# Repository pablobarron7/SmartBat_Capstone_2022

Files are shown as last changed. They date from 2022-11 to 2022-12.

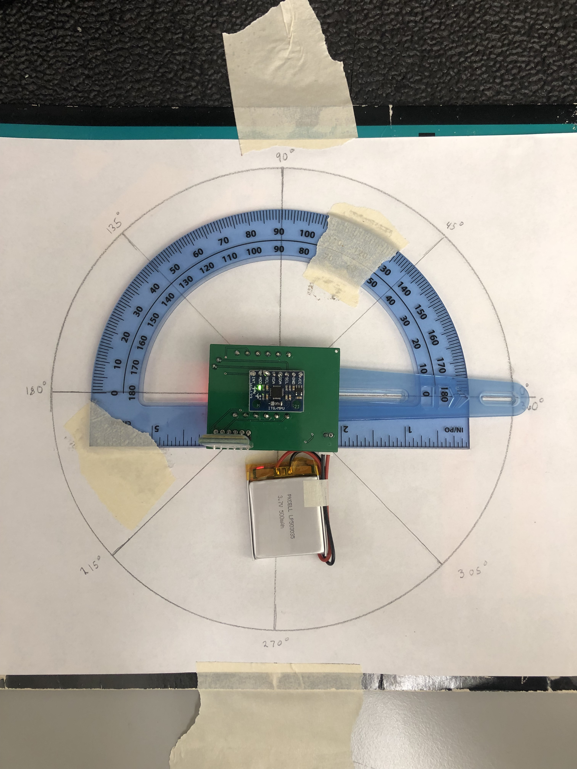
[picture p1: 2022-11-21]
IMU Validation Plots/GyroValidationMethod.jpg

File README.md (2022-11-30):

# SmartBat_Capstone_2022
  The purpose of this project is to allow a Cricket player to get real-time feedback on the user's swing data with out the need of assistance from a coach. The user will be able to view their efficiency, swing speed, and hit location on a user-friendly Android App. 
  
ANDROID APP SUBSYSTEM:
  
  The necessary source files for the android app are located under the "src" folder and include the "build.gradle" and "settings.gradle" files. The Andriod App receives data from our MCU via bluetooth which is then sent to an AWS cloud to be processed by the ML Model. The ML Model will then calcuate the hit location and swing speed. The app will then fetch the calculated results from our AWS Cloud.

CONTROL SUBSYSTEM:
  
  Download the SmartCricketBatOwnCode.ino file, along with the MCU libraries, and use both within Ardunio studio to flash desired ATmega328p microcontroller (make sure  MCU libraries are properly added to Arduino studio's directory after download to avoid any errors). Within the IMU Validation Plots folder are the results from several validation tests performed on the MPU-6050 inertial measurement unit, the plots prove the data recieved from the IMU is accurate, within some margin, to the expected results (raw data text files used to create plots are available within folder as well). 
  
POWER SUBSYSTEM:

  The "FinalPCB" folder contains the EAGLE schematic and PCB board layout files for the project. The PCB contains the battery charging circuit and boost converter circuit  which distribute all the necessary power to the control system. The "powersystemresults" folder contains results for the boost converter load test as well as results for the battery charging circuit.
  
ML SUBSYSTEM:

  All the necessary files are in the ML folder. WIth data collected, "Preprocessing321" to generate features and labels for trainnig the ML. They are named as "feature(1)" and "label(1)". With features and labels, you can traing the model with "Training321" and see the accuracy, heatmap, and feature importance(the seaborn pairplot is comment out). "model1.pkl" is the final model that we use for this project. "sv" is a python file as "sv.py" with stands for server version of my code where it will run on aws EC2 to predict the final results.

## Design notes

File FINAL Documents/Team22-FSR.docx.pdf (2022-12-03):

# Smart Cricket Bat

### Gavin Dahl, Jiakai Hu, Pablo Barron, Nolapat Pipitvitayakul

## FUNCTIONAL SYSTEM REQUIREMENTS

### REVISION – 2 18 November 2022

FUNCTIONAL SYSTEM REQUIREMENTS

FOR

## Smart Cricket Bat

PREPARED BY:

_____________________________
Author | Date

APPROVED BY:

_____________________________
Project Leader | Date

_____________________________
John Lusher, P.E. | Date

_____________________________
T/A | Date

Functional System Requirements | Revision - 2
The Smart Cricket Bat

### Change Record

Rev. | Date | Originator | Approvals | Description
- | 2/23/2022 | Gavin Dahl | | Draft Release
1 | 4/22/2022 | Gavin Dahl | | First Revision
2 | 11/18/2022 | Gavin Dahl | | Final Revision

### Table of Contents

List of Figures | 4
1. Introduction | 5
1.1. Purpose and Scope | 5
1.2. Responsibility and Change Authority | 5
2. Applicable and Reference Documents | 6
2.1. Applicable Documents | 6
2.2. Reference Documents | 6
2.3. Order of Precedence | 7
3. Requirements | 8
3.1. System Definition | 8
3.2. Characteristics | 9
3.2.1. Functional / Performance Requirements | 9
3.2.2. Physical Characteristics | 10
3.2.3. Electrical Characteristics | 11
3.2.4. Environmental Requirements | 13
3.2.5. Failure Propagation | 14
4. Support Requirements | 15
Appendix A Acronyms and Abbreviations | 16

### List of Figures

Figure 1. The Smart Cricket Bat Conceptual Image | 5
Figure 2. Block Diagram of System | 8

## 1. Introduction

### 1.1. Purpose and Scope

Our purpose is to help users improve their cricket skill through a training session using our system. The sensing unit will be attached to the end of the bat. This unit shall last for six hours of battery life after fully charged. The sensors will receive data and transfer them via bluetooth to an android phone app. The ML algorithm shall calculate the necessary data to the ones that need to be shown on the phone app like the hit location, swing angle and speed. The users shall be able to access these data through the phone app. The users will be able to know whether their hit was on the “sweet spot” or not as well as how efficient their swing was.

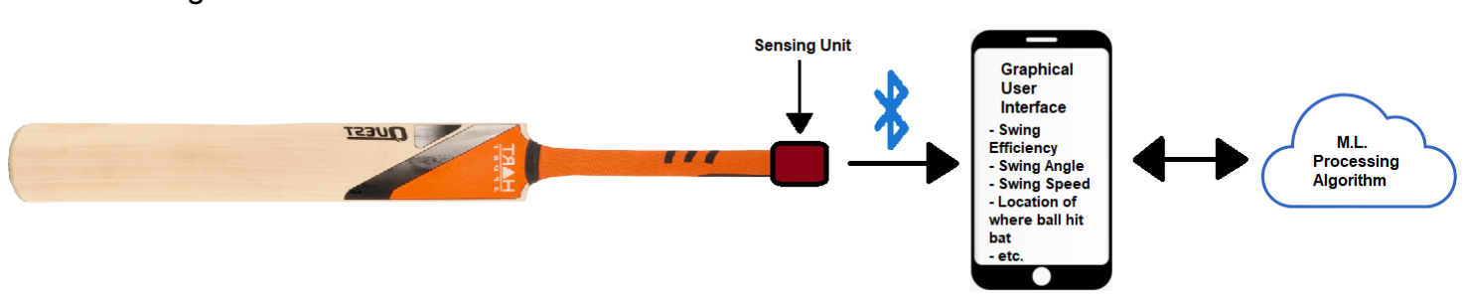
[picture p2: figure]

Figure 1. The Smart Cricket Bat Conceptual Image

### 1.2. Responsibility and Change Authority

Gavin Dahl has the responsibilities of making sure the team is sticking to the execution plan, completing milestones, and producing deliverables. He is also responsible for making the team confined to deadlines. The team's sponsor, Pranav Dhulipala, is the only one with the authority to make changes to the end goal requirements. If there is an unforeseen element that causes us to be unable to meet a requirement, Gavin and Pranav will discuss what will need to be done to change the requirement.

## 2. Applicable and Reference Documents

### 2.1. Applicable Documents

The following documents, of the exact issue and revision shown, form a part of this specification to the extent specified herein:

Document Number | Revision/Release Date | Document Title
IEEE 1780-2022 | 2022-02-09 | Standard for the Specification of Inertial Measurement Units
10.1109/ICIAFS.2008.4783 997 | 2009-02-13 | Design and Implementation of a Bluetooth based General Purpose Controlling Module
IEEE 802.15.1 | 2005-02-14 | Standard for Telecommunications and Information Exchange Between Systems
IEEE 802.15.4 | 2020-05-06 | Standard for Low-Rate Wireless Networks

### 2.2. Reference Documents

The following documents are reference documents utilized in the development of this specification. These documents do not form a part of this specification and are not controlled by their reference herein.

Link | Document Title
https://www.cricketequipmentusa.com/cricke t-bats-specifications-recent-changes-to-the-l aw-52#:~:text=Length%20and%20width%2 0of%20the,than%2052%25%20of%20the% 20bat (https://www.cricketequipmentusa.com/cricket-bats-specifications-recent-changes-to-the-law-52) | CRICKET BATS SPECIFICATIONS -RECENT CHANGES TO THE LAW
https://www.stancebeam.com/ | Stance Beam
https://www.google.com/url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 m%2Fpaper%2Fdownload%2F362441%2F mulchand_paper.pdf&usg=AOvVaw05RGQ GwEzXQR0SqdD7-Cp9 (https://cn.comsol.com/paper/download/362441/mulchand_paper.pdf) | Determination of the “Sweet Spot” of a Cricket Bat using COMSOL Multiphysics

### 2.3. Order of Precedence

In the event of a conflict between the text of this specification and an applicable document cited herein, the text of this specification takes precedence without any exceptions.

All specifications, standards, exhibits, drawings or other documents that are invoked as “applicable” in this specification are incorporated as cited. All documents that are referred to within an applicable report are considered to be for guidance and information only, except ICDs that have their relevant documents considered to be incorporated as cited.

## 3. Requirements

### 3.1. System Definition

In cricket, ball placement on the bat is very crucial to maximize the points you receive. To better improve a player's ball placement, we will design a device that can be attached to any cricket bat and predict the location of the collision between the bat and the ball. The device will be powered by a rechargeable lithium battery with a battery life of six hours. Data will then be gathered via a 3-axis accelerometer and gyroscope. A MCU will then send the data via bluetooth to an Android app to send to a server-based machine learning algorithm to predict the location of the collision. All results will then be displayed on the app.

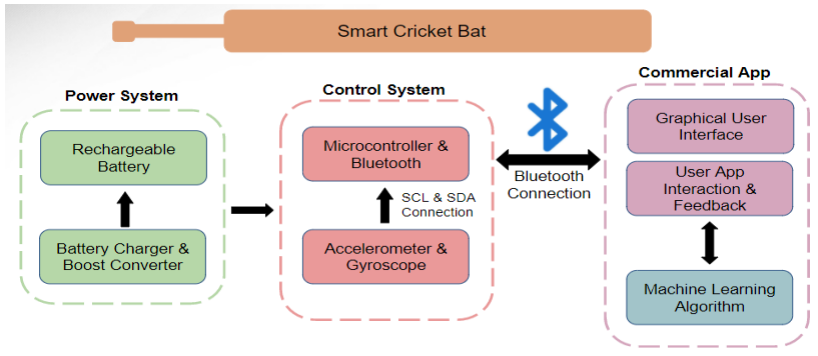
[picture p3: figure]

Figure 2. Block Diagram of System

The block diagram above shows the individual subsystems of the device. The subsystems include: Power System, Control System, and Commercial App. The device will be powered by a lithium battery connected to a boost converter to deliver the necessary power requirement for the control system. This battery will be connected to the control system through a PCB, that will also hold the charging circuit for the battery that will require a mircoUSB to charge. The control system encompasses a 3-axis accelerometer, a 3-axis gyroscope and a ATmega328p microprocessor. The angular momentum and rate of change data we measured with the gyroscope and accelerometer will then connect and be sent via bluetooth to the commercial app. The commercial app will then send the data to a machine learning algorithm via an internet connection to calculate collision location and efficiency. The results of the device will then be displayed on the easy to use app. Each output variable will have its own designated page to be viewed.

### 3.2. Characteristics

### 3.2.1. Functional / Performance Requirements

### 3.2.1.1. Calibration

The device must be able to be calibrated to properly calculate results. The process of calibration will entail leaving the device at rest in an upright position, and pushing the calibration button on the corresponding mobile app.

Rationale: The IMU sensor used in the device needs to be calibrated after start-up to deliver accurate and clean data to the machine learning algorithm. Calibrating the device
before usage will result in a higher certainty percentage.

### 3.2.1.2. Collision Location Determination

The main function of the device will be able to determine the location of the collision between the cricket bat and the ball based on the magnitude of the force felt by the bat and the torque produced by the ball on the bat, which is obtained from the data measured by the IMU sensor. The certainty must be at least 90%. This will require a machine learning (ML) algorithm.

Rationale: Cricket players will use the device to improve their swing efficiency. The location of the collision will dictate how far and in which direction the ball will go. Depending on where the ball lands on the field is how many turns (points) a player can achieve. Therefore, knowing where the ball collides with the bat is crucial for the player to know.

### 3.2.1.3. Efficiency Calculation

The device will be able to calculate how efficient the user is swinging the bat based on gathered data from previous swings. Efficiency is determined by how close the collision was to the “sweet spot” of the bat. The sweet spot of a cricket bat is located on the thickest section of the bat and is different for each cricket bat.

Rationale: Based on the efficiency the user will be able to tell how far off from the sweet
spot their swing is.

### 3.2.1.4. Bluetooth Range

The device will be able to communicate with the app within a range of 50m.

Rationale: The user should be able to do their practice swings with their phone clear from any danger of being hit while in the batting box.

### 3.2.1.5. Easy to Use App/GUI

The app will be easy navigable and easy to read the outputs

Rationale: The user might not have programming or data analysis skills so having an app that anyone can use and read is crucial for the device to be successful in the cricket market.

### 3.2.1.6. Battery Life

The device will be powered by a lithium battery that must have a battery life of 2 hours and must be rechargeable.

Rationale: Battery life and rechargeability were requirements set by the customer.

### 3.2.2. Physical Characteristics

### 3.2.2.1. Mass

The mass of the sensing unit that mounts to the handle of the cricket bat should be no more than 100g.

Rationale: This is a requirement specified by the sponsor due to wanting the device to be
as unobtrusive to the users swing as possible.

### 3.2.2.2. Volume Envelope

The volume envelope of the smart cricket bat’s sensor unit shall be less than or equal to 40mm in height, 70mm in outer diameter.

Rationale: This is a requirement specified by the sponsor due to wanting the device to be
as unobtrusive to the users swing as possible.

### 3.2.2.3. Mounting

The mounting device will attach to the bottom of the cricket bat’s handle and will have a locking mechanism with the sensor unit to give it a secure fit.

Rationale: The vibrations that occur from the impact of a swing can be quite intense. The requirement is to have the device stay on the bat at all times during the user's use, through any kind of outside interference.

### 3.2.3. Electrical Characteristics

### 3.2.3.1. Inputs

a. The presence or absence of any combination of the input signals in accordance with ICD specifications applied in any sequence shall not damage the smart cricket bat, reduce its life expectancy, or cause any malfunction, either when the unit is powered or when it is not.
b. No sequence of command shall damage the smart cricket bat, reduce its life expectancy, or cause any malfunction.

Rationale: By design, should limit the chance of damage or malfunction by user/technician error.

### 3.2.3.1.1 Power Consumption

The maximum peak power of the system shall not exceed 300 mW.

Rationale: This requirement is to ensure that enough power is being supplied to each of the components for at least 2 hours when the battery is fully charged.

### 3.2.3.1.2 Input Voltage Level

The input voltage level for the MCU and the IMU shall be +5 V.

Rationale: The microcontroller’s operating voltage is 5V and the IMU input voltage can be between 3.3V to 5V.

### 3.2.3.1.3 External Commands

The smart cricket bat shall document all external commands in the appropriate ICD.

Rationale: The ICD will capture all interface details from the low level electrical to the high-level packet format.

### 3.2.3.2. Outputs

### 3.2.3.2.1 Data Output via App

The app will be able to output data gathered from the accelerometer and gyroscope and the calculated results from the ML algorithm. The outputs will include: swing speed, swing angle, collision location, and efficiency. Each output will have its own page the user can navigate to via buttons on the home screen.

Rationale: By having an app that can constantly be gathering and outputting data in an
easy to read manner, it eliminates the need for the user to have tech. and data analysis skills. Without the app, users will have to download the data onto their computer to view
their results.

### 3.2.3.3. Connectors

The smart cricket bat will use a microUSB to charge the sensor unit, and will also be able to get the sensor data via a microUSB in the case of bluetooth not working.

Rationale: Most efficient way to make the device is to make it rechargeable, so that it
can be as small and light as possible.

### 3.2.3.4. Wiring

The smart cricket bat will use a PCB to connect all the internal components (MCU, IMU, Li-Po Battery, Boost Convertor/Charger) of the sensor unit.

Rationale: Normal wiring will most likely not be secure or robust enough for the amount
of shock that the device will encounter.

### 3.2.4. Environmental Requirements

The device will be adequate for indoor and outdoor use.

Rationale: Although the device will not be used during a cricket match, a user might be holding their practice session indoors or outdoors.

### 3.2.4.1. Pressure (Altitude)

The device will be designed to operate in 1 atm pressure.

### 3.2.4.2. Temperature

The device will be able to operate between temperature ranges of 0°C to 85°C.

Rationale: Since the device can be used outdoors, temperatures during the summer in Texas are between 97℉ - 105℉.

### 3.2.4.3. External Contamination

The device will be housed in a casing to protect the components from any dirt or foreign objects.

Rationale: Since the device can be used outdoors, it must be protected from any materials that can cause damage to the components.

### 3.2.4.4. Rain

The device will not be able to be used during the rain, but it should be waterproof enough to protect the components from the sweat of the user. The device will operate as intended within the humidity range of 0 to 80%, and should have the possibility of correct operation through 90 to 100%.

### 3.2.5. Failure Propagation

The smart cricket bat shall not allow propagation of faults beyond the app's interface.

### 3.2.5.1. Failure Detection, Isolation, and Recovery (FDIR)

### 3.2.5.1.1 Communication Test

The Smart Cricket Bat System shall provide users a notification if the user is using the system out of range or the internet/bluetooth connection is unstable at this moment.

### 3.2.5.1.1.1 BIT Critical Fault Detection

The BIT shall be able to detect a critical fault in the smart cricket bat’s sensing unit, machine learning algorithm, or consumer app, 95 percent of the time.

Rationale: This is to provide the best user experience we can, letting the user know that
we know there is an error and the system is working to fix it.

### 3.2.5.1.1.2 BIT False Alarms

The BIT shall have a false alarm rate of less than 5 percent.

Rationale: Due to some of the possible erroneous uses of the cricket bat, it might interpret an action of the user as an error, when in reality it is not.

### 3.2.5.1.1.3 BIT Log

The BIT shall save the results of each test to a log that shall be stored in the machine learning system for retrieval and will be used to improve common errors and overall quality of life of the user experience.

Rationale: The device is very user focused, so providing the best user experience is of
high priority.

### 3.2.5.1.2 Isolation and Recovery

The smart cricket bat should provide for fault isolation and recovery by enabling subsystems to be disabled based upon the result of the BIT.

Rationale: If there are any errors, we want to turn the device off and let the user know to
stop using it so they aren’t wasting energy on swings that will not be analyzed.

## 4. Support Requirements

The user will be provided with a user’s manual to know how to properly use the device. The user’s manual will encompass how to calibrate the device to be used in different sized cricket bats, the different functions of the app, ie. efficiency and swing speed, and how to charge the device. If any problems occur with the device, the user can send the device back to be fixed.

## Appendix A: Acronyms and Abbreviations

m | Meter
mm | Millimeter
mA | Milliamp
mAh | Milliamp-hour
mW | Milliwatt
V | Volt
MCU | Microcontroller
IMU | Inertial Measurement Unit (Accelerometer & Gyroscope)
PCB | Printed Circuit Board
LiPo | Lithium Polymer Battery
BLE | Bluetooth Low Energy
GUI | Graphical User Interface
BIT | Built-in-test

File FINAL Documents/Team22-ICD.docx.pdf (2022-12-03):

# Smart Cricket Bat

### Gavin Dahl, Jiakai Hu, Pablo Barron, Nolapat Pipitvitayakul

## INTERFACE CONTROL DOCUMENT

### REVISION – 1 18 November 2022

INTERFACE CONTROL DOCUMENT

FOR

## Smart Cricket Bat

PREPARED BY:

_____________________________
Author | Date

APPROVED BY:

_____________________________
Project Leader | Date

_____________________________
John Lusher II, P.E. | Date

_____________________________
T/A | Date

Interface Control Document | Revision - 1
Smart Cricket Bat

### Change Record

Rev. | Date | Originator | Approvals | Description
- | 2/23/2022 | Gavin Dahl | | Draft Release
1 | 11/18/2022 | Gavin Dahl | | Final Revision

### Table of Contents

List of Figures | 4
1. Overview | 4
2. References and Definitions | 5
2.1. References | 5
2.2. Definitions | 5
3. Physical Interface | 6
3.1. Weight | 6
3.2. Dimensions | 6
3.2.1. Dimensions of Power System | 6
3.2.2. Dimensions of Control System | 6
3.3. Mounting Locations | 6
4. Thermal Interface | 7
5. Electrical Interface | 8
5.1. Primary Input Power | 8
5.2. Signal Interfaces | 8
5.3. User Control Interface | 8
6. Communications / Device Interface Protocols | 9
6.1. Wireless Communications (Bluetooth & Internet ) | 9
6.2. G.U.I. | 9
6.3 | Device Peripheral Interface | 9

### List of Figures

Figure 1: Mounting Locations on Bat | 7
Figure 2: Sample UI | 10

## 1. Overview

In this ICD, the details for physical dimensions and weight will be provided in section 3. The sensing unit will be attached to the end of the bat, the details for attaching will also be provided. This unit does not have a cooling system. Temperature limits will be shown in section 4. This unit shall last for two hours of battery life after fully charged. The electrical details and thresholds for sensors and the whole system are listed in section 5. The details for communication between systems and the user control interface are provided in the last section.

## 2. References and Definitions

### 2.1. References

- Reference Device:
- https://www.stancebeam.com/
- Standard for the Specification of IMU’s:
- https://standards.ieee.org/ieee/1780/5700/
- Cricket Bat Standard:
- https://www.cricketequipmentusa.com/cricket-bats-specifications-recent-changes-to-the-law-52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,than%2052 %25%20of%20the%20bat. (https://www.cricketequipmentusa.com/cricket-bats-specifications-recent-changes-to-the-law-52)
- Determination of the “Sweet Spot” of a Cricket Bat using COMSOL Multiphysics
- https://www.google.com/url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 (https://cn.comsol.com/paper/download/362441/mulchand_paper.pdf)

### 2.2. Definitions

m | Meter
mm | Millimeter
mA | Milliamp
mAh | Milliamp-hour
mW | Milliwatt
V | Volt
MCU | Microcontroller
IMU | Inertial Measurement Unit (Accelerometer & Gyroscope)
LiPo | Lithium Polymer Battery
BLE | Bluetooth Low Energy
SCL | Serial Clock Line
SDA | Serial Data Line

## 3. Physical Interface

### 3.1. Weight

The goal is to keep the weight as low as possible, to not interfere with the players swing. The exact weight of the housing unit that will hold the components is still unknown, but ideally will be around 50 grams. The internal components of the device approximately add up to 40 grams. Weighing the device as a whole, including both the housing unit and the device internals, it will be less than 100 grams.

### 3.2. Dimensions

The mounting device's interior restriction is limited by the internal components of the device, which will be around 30mm x 35mm x 30mm. The exact dimensions of the housing unit for the device is still unknown, but basing them off the known restrictions for internals of the device, it should be approximately 35mm x 40mm x 35mm, with the goal being to make it a cylindrical mounting device that will have a diameter of about 60mm and height of 35mm.

### 3.2.1. Dimension of the power system

The power system itself, being composed of 1 Li-Po battery and 1 boost converter/recharging station, makes up approximately 33mm x 20mm x 14mm

### 3.2.2. Dimension of the control system

The control system is made up of 1 Beetle BLE MCU and 1 6-axis IMU sensor (containing a 3-axis gyroscope and a 3-axis accelerometer), totaling up to approximately 30mm x 35mm x 8mm.

### 3.3. Mounting Locations

The mounting location will be at the end of the cricket bat’s handle. It will use a kind of sleeve that is put over a little more handle and will securely lock together with the housing device for the control and power systems. If there are any complications with trying to mount the device in this location, the back up spot for mounting will be on the back of the bat at the other end of the handle.

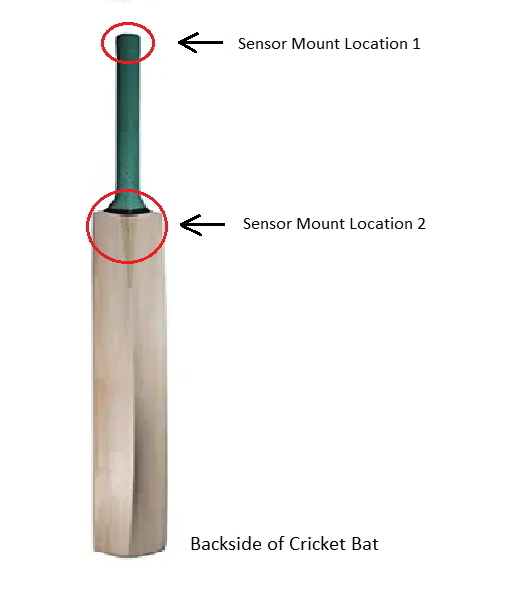
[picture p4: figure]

Figure 1: Mounting Locations on Bat

## 4. Thermal Interface

Since our device will be small enough to be attached to the bottom of a cricket bat, there will not be a need for fans or heat sinks for cooling. The only thermal interface our device will require is having vents or perforations on the main housing of the MCU and IMU’s to allow airflow, as the MCU is the limiting factor and cannot run properly over 85°C (185°F). This will prevent overheating in case the user is using our device outdoors on a summer’s day.

## 5. Electrical Interface

### 5.1. Primary Input Power

Power will be supplied by a rechargeable 3.7V lithium ion polymer battery with 500mAh capacity. The voltage will be regulated and the boost converter will convert the voltage to 5V, which is within the acceptable range of input voltage levels for the MCU and the sensors.

### 5.2. Signal Interfaces

The signal interfaces are the input to the MCU from the IMU sensor containing a 3-axis gyroscope and a 3-axis accelerometer. The IMU sensor module uses SCL/SDA for communicating with the microcontroller.

### 5.3. User Control Interface

The interface with the user will be an android app which will display the data collected by the IMU sensor as well as the data for the location of collision with the ball and the efficiency of the user’s swing predicted by a machine learning algorithm.

## 6. Communications / Device Interface Protocols

### 6.1. Wireless Communications (Bluetooth & Internet )

Our device will communicate with our app via bluetooth, which will have a connectivity range of about 50m. The app itself will also connect to our machine learning algorithm, that's stored in the cloud, via an internet connection.

### 6.2. GUI

All user interactions with our device will be controlled by an android app. These interactions will include calibration of our device and data output. The user will be able to navigate through different pages of the app via designated buttons on the home screen. A screen show of the buttons on the dashboard is shown below.

Figure 2: Sample UI

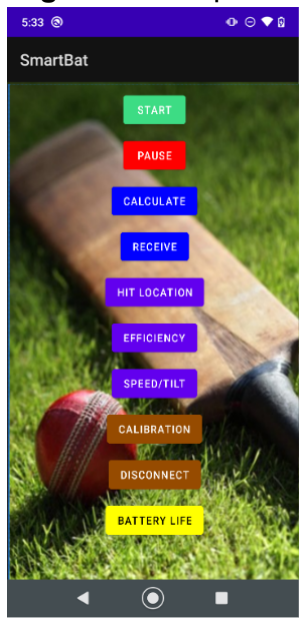
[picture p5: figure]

### 6.3. Device Peripheral Interface

The MCU and IMU will communicate with each other via a SCL and SDA connection. This connection allows the SCL to be the synchronized clock signal between the MCU and IMU for data transfer over the IC2 bus, and SDA is the data line that holds the actual data.

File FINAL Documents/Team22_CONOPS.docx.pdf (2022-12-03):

# Smart Cricket Bat

### Gavin Dahl, Jiakai Hu, Pablo Barron, Nolapat Pipitvitayakul

## CONCEPT OF OPERATIONS

### REVISION – 2 17 November 2022

CONCEPT OF OPERATIONS

FOR

## Smart Cricket Bat

TEAM <22>

APPROVED BY:

_____________________________
Project Leader | Date

_____________________________
Prof. Kalafatis | Date

_____________________________
T/A | Date

Concept of Operations | Revision - 2
Smart Cricket Bat

### Change Record

Rev. | Date | Originator | Approvals | Description
- | 2/9/2022 | Pablo Barron | | Draft Release
1 | 2/23/2022 | Pablo Barron | | First Revision
2 | 11/17/2022 | Gavin Dahl | | Final Revision

### Table of Contents

Table of Contents | 3
List of Figures | 4
1. Executive Summary | 6
2. Introduction | 7
2.1. Background | 7
2.2. Overview | 7
2.3. Referenced Documents and Standards | 7
3. Operating Concept | 8
3.1. Scope | 8
3.2. Operational Description and Constraints | 8
3.3. System Description | 8
3.4. Modes of Operations | 9
3.5. Users | 9
3.6. Support | 10
4. Scenario(s) | 11
4.1. Indoor Cricket Batting Practice | 11
4.2. Outdoor Cricket Batting Practice | 11
5. Analysis | 11
5.1. Summary of Proposed Improvements | 11
5.2. Disadvantages and Limitations | 11
5.3. Alternatives | 11
5.4. Impact | 12

### List of Figures

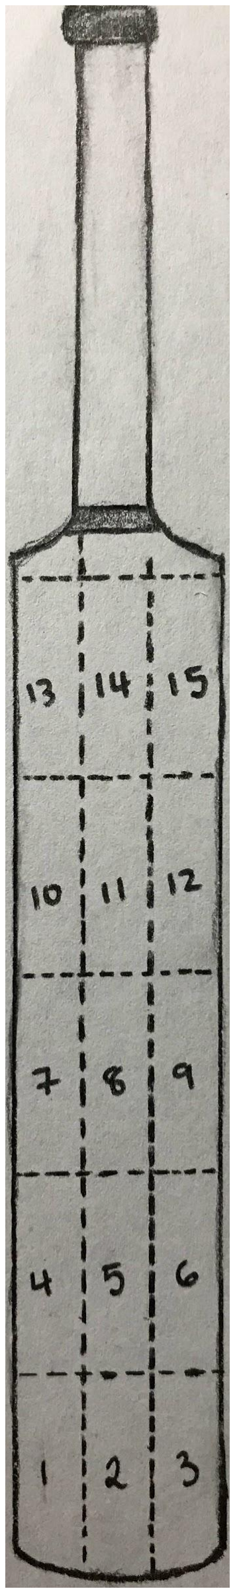
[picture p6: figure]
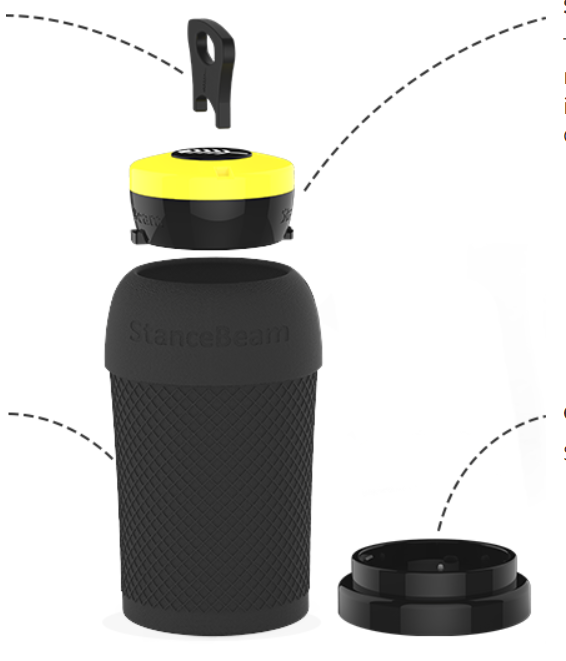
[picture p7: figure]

Fig. 1: Cricket Bat Region Subdivision Fig.2: StanceBeam Device Charging Dock on the right. Main hardware housing is in yellow. The mounting to attach to the bat below the main hardware housing. Figure above the main housing is to lock the device in place

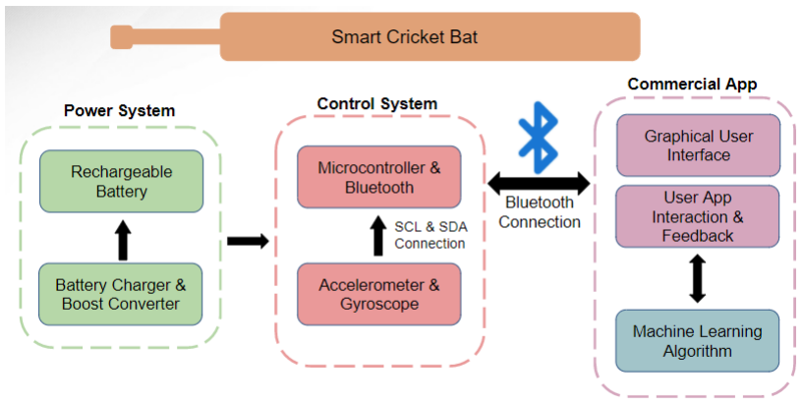
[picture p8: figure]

Fig.3: Subsystem Block Diagram

## 1. Executive Summary

While cricket has been around for much longer than its contemporary baseball, there is a stark difference in training equipment available for casual enjoyers, the smart cricket bat plans to fill that space. The smart cricket bat offers an easy at home alternative to coaching lessons in the form of an app and a device you put on your cricket bat of choice. The app will display measurements and calculations from the bat, such as the angle of the swing, the speed of the swing, the efficiency of the user’s swing, and the approximate position of where the ball hit the bat. The last of which is found via a machine learning algorithm that takes the other measurements and triangulates the impact location. This will help improve both accuracy and precision when swinging for the bats sweet spot.

## 2. Introduction

Cricket is more of a niche sport than others, so it’s no surprise that the community overall is lacking in training and feedback equipment. Most of the training equipment they do have are primarily rudimentary items, such as ball rebounders, batting tees, etc. And recently, one start up, StanceBeam, that is trying to provide easier at home training is a little on the expensive side. The smart cricket bat will fill this gap by providing a device that will attach to the user’s cricket bat of choice and acquire various data points on each swing. This device will then connect to the player's phone via bluetooth, process the data acquired from the sensors on the bat, and give real time feedback to help the user.

### 2.1. Background

In cricket, the goal is to score runs, this is accomplished through completing runs, hitting boundaries, losing wickets, and free runs. Half of these, completing runs and hitting boundaries, involve hitting the ball into a desired area of the field, to accomplish these feats easier the cricket bat is designed to have a “sweet spot” where the bat is thicker than everywhere else, thus having more force behind it. The goal is to have a consistent enough swing to hit the sweet spot as often as possible. StanceBeam is a start-up out of India that is trying to help the average player with this. Their product is a sensor that connects to an app and displays measurements from the bat such as swing angle, swing speed, power generated from swing, and overall swing efficiency. The app also has drills and real-time coaching from real coaches to help improve aspects of their play. In contrast, the app will display where the ball impacted the bat via a histogram and give advice for improvement, as well as displaying swing angle, swing speed, and overall swing efficiency. Despite being limited in the ability to display drills or video analysis, the Smart Cricket Bat will be able to help the user improve swing consistency and ball placement, specifically for the bats sweet spot, through the use of small advice and a histogram from swing data.

### 2.2. Overview

The overall goal of the smart cricket bat is to deliver concise, analyzed data from the users swings to the app and give real-time feedback to the user to help improve their overall swing consistency and efficiency. This will be accomplished by a device that will mount to the end of the cricket bats handle and collect both speed and angle of the cricket bat during the user swing. It then sends that data to the smartphone app via bluetooth to process the data, through a machine learning algorithm, and output real time feedback to the user.

### 2.3. Referenced Documents and Standards

- Reference Device:
- https://www.stancebeam.com/
- Standard for the Specification of IMU’s:
- https://standards.ieee.org/ieee/1780/5700/
- Cricket Bat Standard:

- https://www.cricketequipmentusa.com/cricket-bats-specifications-recent-changes-to-the-law-52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,than%2052 %25%20of%20the%20bat. (https://www.cricketequipmentusa.com/cricket-bats-specifications-recent-changes-to-the-law-52)
- Determination of the “Sweet Spot” of a Cricket Bat using COMSOL Multiphysics
- https://www.google.com/url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 (https://cn.comsol.com/paper/download/362441/mulchand_paper.pdf)

## 3. Operating Concept

### 3.1. Scope

The main functionality of the smart cricket bat will be to calculate where on the bat the ball hits based on data gathered from a gyroscope and an accelerometer. Based on data collected from the gyroscope and accelerometer, the speed of the swing and angle of the swing will be calculated by an offline machine learning algorithm. The data gathered from the IMU sensors will be sent via bluetooth to an app. From the gathered data and ML algorithm results, the app will display to the user with a histogram of where on the bat the ball collided. From the data on the histogram, how efficient the user is hitting the ball will be calculated. The app will also show details of every swing ie. speed of the swing and swing angle.

### 3.2. Operational Description and Constraints

The device will be attached on the bottom of the handle of the bat. Once the device is attached, it will need to be calibrated to accurately measure collision location and efficiency. The calibration of the device will be the main constraint, since failure to properly calibrate the device will lead to false data being produced. The calibration step will be a simple button press while the bat is resting in an upright position. Once calibrated, the user will be able to practice for about six hours on full battery. During the user’s practice session or after the session, the user can check the app to view the data gathered for each swing. Once the battery is drained or the user’s practice session is finished, the user will need to recharge the device via a micro-USB cable. Another constraint for the device is size and weight. The device must be small enough to attach to the bottom of the handle on the cricket bat and light enough to not affect the overall feel of the bat and performance of the user.

### 3.3. System Description

- Power: The device will be powered by a lithium battery with a battery life of about six hours. The device will be rechargeable via a micro-USB cable.
- Sensors and Microcontroller: The sensors (IMU) will encompass one 3-axis accelerometer and one 3-axis gyroscope. The device will gather the angular velocity and rate of change from the IMU and transfer data via bluetooth to be processed in a machine learning algorithm.

- App: The app will receive data from the MCU and send the data to an offline machine learning algorithm to calculate and predict the location of collision and the efficiency of the user’s swing. Once the region of collision and efficiency is determined, the app will display a histogram of the different collisions that occurred during the user’s training session. It will also display the swing speed, swing angle, and efficiency of the user.

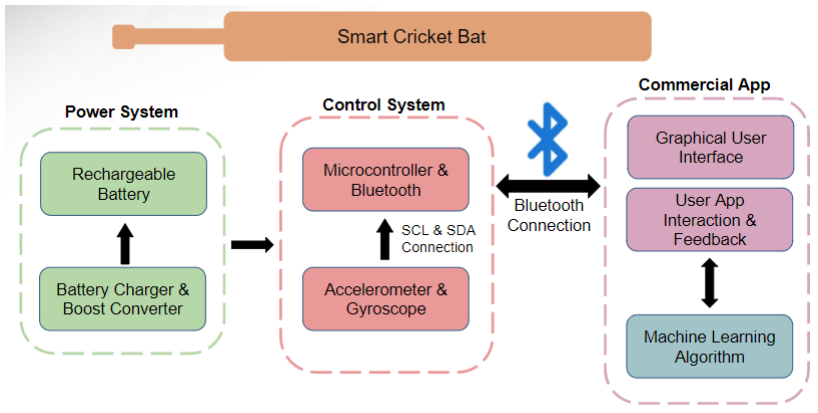
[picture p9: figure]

Figure 1: Subsystem block diagram

### 3.4. Modes of Operations

The device will have two modes of operation:
- Calibration Mode: Before the user can use the device, the device needs to be calibrated, doing so is as simple as pushing a button on the mobile application while the device is at rest in the upward position.
- Practice Mode: Once the device is calibrated, the user is now able to begin their training session. The device will have a six hour battery life. During the training session, the microprocessor will send data gathered from the IMU to the app to be sent to a server housing the machine learning algorithm to determine the location of collision and the efficiency of the user. The app will then display a histogram to show the collision location of each swing, the speed of the swing, swing angle, and user’s efficiency.

### 3.5. Users

The main users will be cricket players trying to improve their swing. Their experience with cricket will range from grade-school level to professional players. The necessary skill level to operate the device is knowing how to use a phone app and read a histogram.

### 3.6. Support

The user will be provided with a user’s manual to know how to properly use the device. The user’s manual will encompass how to calibrate the device to be used in different sized cricket bats, the different functions of the app, ie. efficiency and swing speed, and how to charge the device. If any problems occur with the device, the user can send the device back to be fixed.

## 4. Scenario(s)

### 4.1. Indoor Cricket Batting Practice

The first scenario for the smart cricket bat is the user uses the device to practice their swing in an indoor training environment. In this scenario, the only potential damage that the device will encounter is the energy transfer of the ball and the bat colliding and potential sweat from the user. The device will have to be able to work efficiently under these conditions

### 4.2. Outdoor Cricket Batting Practice

The second scenario is if the user wants to use the device to practice their swing in an outdoor training environment. In this scenario, many potential damages can occur. The device will need to not only withstand the conditions of the indoor scenario, but also take into account dirt, water, and extreme temperatures, for both cold and heat.

## 5. Analysis

### 5.1. Summary of Proposed Improvements

The device will offer a user-friendly app and system to allow them to increase the efficiency of their swing by seeing real time data and details on each swing. This device will be able to work on any size of cricket due to the required calibration mode prior to beginning a practice session.

### 5.2. Disadvantages and Limitations

- There is a limitation to the size of the system because it should be small enough to fit on to the bottom of the cricket bat handle.
- Unable to record video for each swings and analyze the video
- The device cannot be too heavy to disrupt the feel of a natural cricket bat
- Every user hold the bat differently, which can cause inconsistencies in the data collection and calculations

### 5.3. Alternatives

- The sensors could be attached to the back of the cricket bat instead of on the handle if size is an issue. Although we opposed from using this design due to a high risk of damaging the sensors due to the energy transfer from the collision of the ball and the cricket bat
- Additional sensors can be added to improve the accuracy of the results.

### 5.4. Impact

- This project will help cricket players study and improve the user’s batting performance.
- If the device becomes as popular as cricket, it can cause an increase in the need for lithium batteries. This higher demand will then cause the mining of lithium and other raw metals to increase.
- The device has the potential to reduce the need for cricket trainers.

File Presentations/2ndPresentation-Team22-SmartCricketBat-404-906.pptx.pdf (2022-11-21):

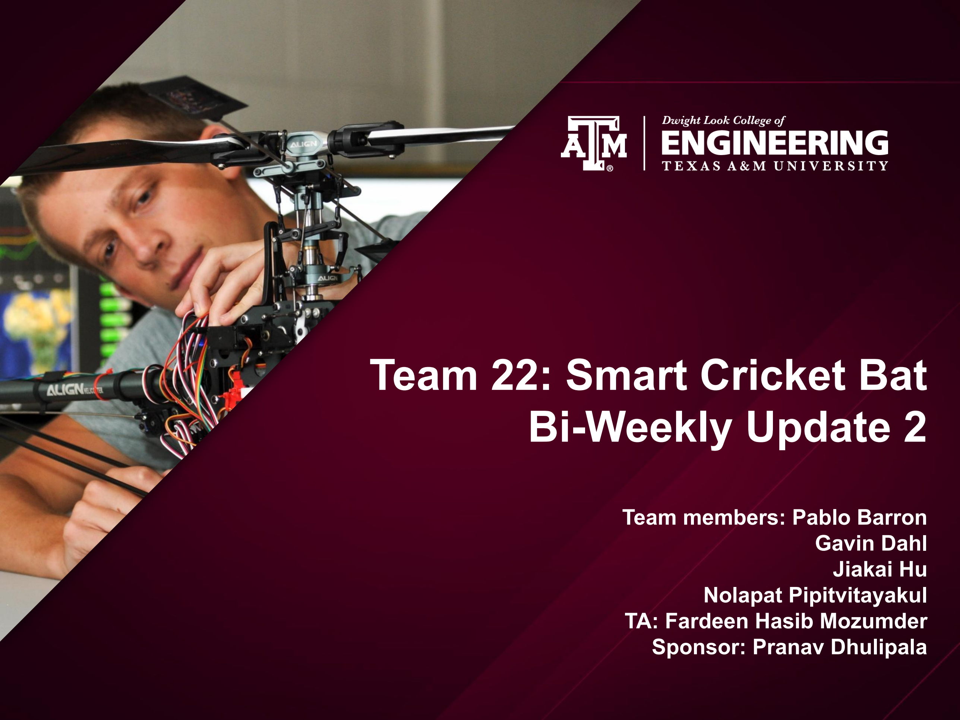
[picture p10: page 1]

# Team 22: Smart Cricket Bat Bi-Weekly Update 2

Team members: Pablo Barron Gavin Dahl
Jiakai Hu
Nolapat Pipitvitayakul
TA: Fardeen Hasib Mozumder Sponsor: Pranav Dhulipala

# Project description

## - Problem: “Cricket practice equipment lacks effectiveness without the assistance and guidance of a coach”

## - Solution proposal: “Create a device that will mount on the cricket bat and, through a user friendly app, gives real time feedback on the user’s cricket swing i.e. efficiency and swing angle. Must be easy to use and set up”

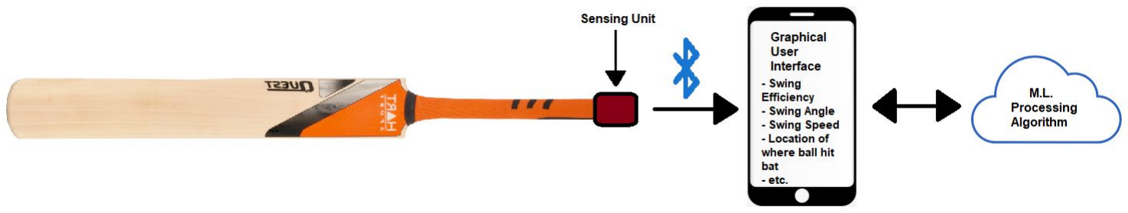
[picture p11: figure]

# Diagram of subsystems and interface

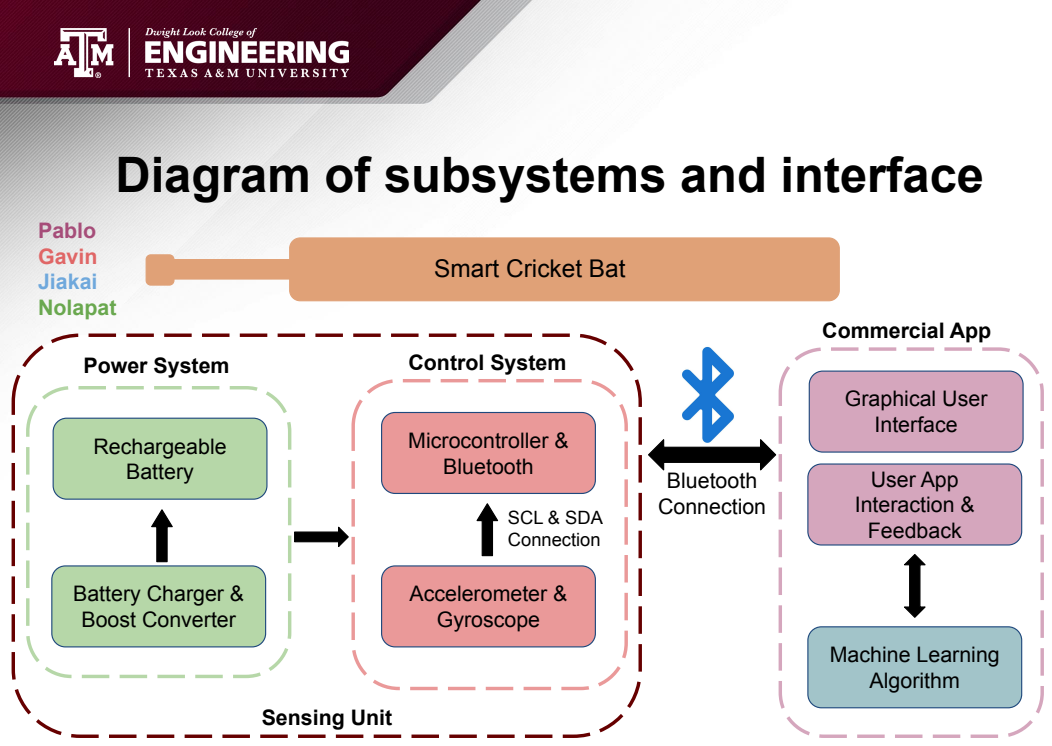
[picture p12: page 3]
Rechargeable; Battery; User App; Interaction & Feedback; Machine Learning Algorithm; Microcontroller & Bluetooth; Accelerometer & Gyroscope; Battery Charger & Boost Converter; Bluetooth Connection; Power System; Control System; Commercial App; Graphical User Interface; Pablo Gavin Jiakai Nolapat; SCL & SDA Connection; Sensing Unit

Smart Cricket Bat

# Subsystem Overview

# - Android App: Will handle user interaction and

communication between the MCU and the ML algorithm.

The app receives data from the MCU via a bluetooth connection. The app will then send received data to ML algorithm to be processed - Power: Contains the boost-converter, on-board lithium battery power supply, and recharging station - ML Algorithm: Develop the ML algorithm for finding the specific characteristics of users swing - Control : A sensing unit that will communicate the IMU values from the swing to the user app through an MCU with bluetooth capabilities

# Project Timeline

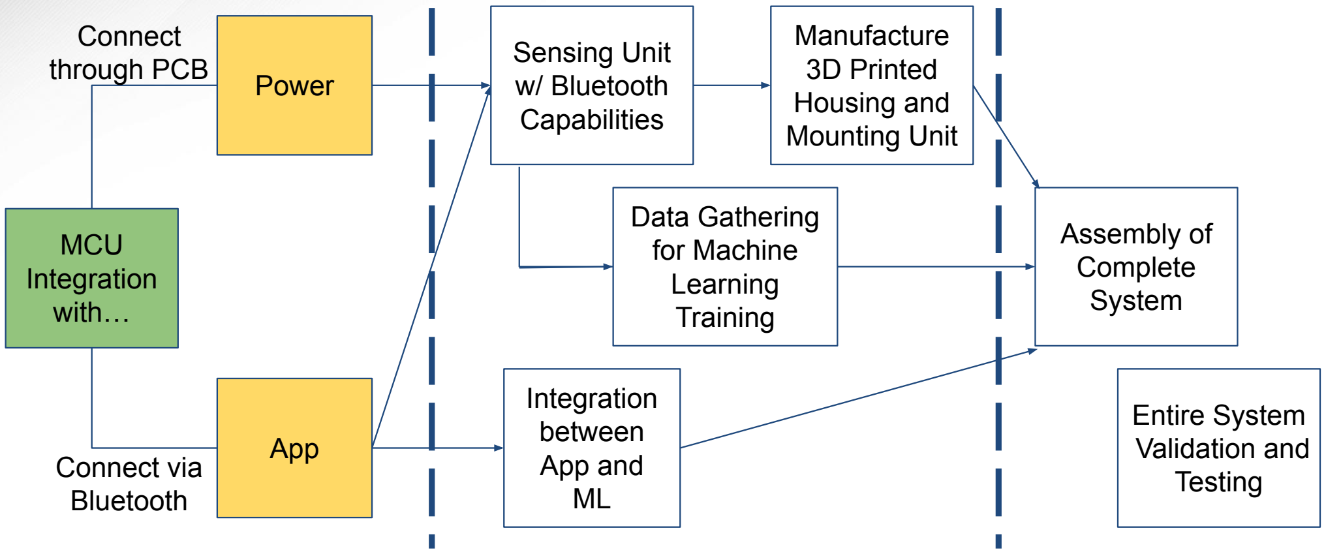
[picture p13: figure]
MCU Integration with…; Power; App Connect via; Bluetooth; Sensing Unit w/ Bluetooth Capabilities; Integration between App and ML; Data Gathering for Machine Learning Training; Entire System Validation and Testing; Assembly of Complete System; Manufacture 3D Printed Housing and Mounting Unit; Connect through PCB

9/2 - 9/30 | 9/30 - 10/28 | 10/28 - 12/2

Control System | Gavin Dahl
Accomplishments since 403 28 hr of effort | Ongoing progress/problems and plans until the next presentation
- Power and Control PCB designed and ordered. | ● Assemble PCB ● Continue work on MCU and App integration through bluetooth ● Optimize MCU code

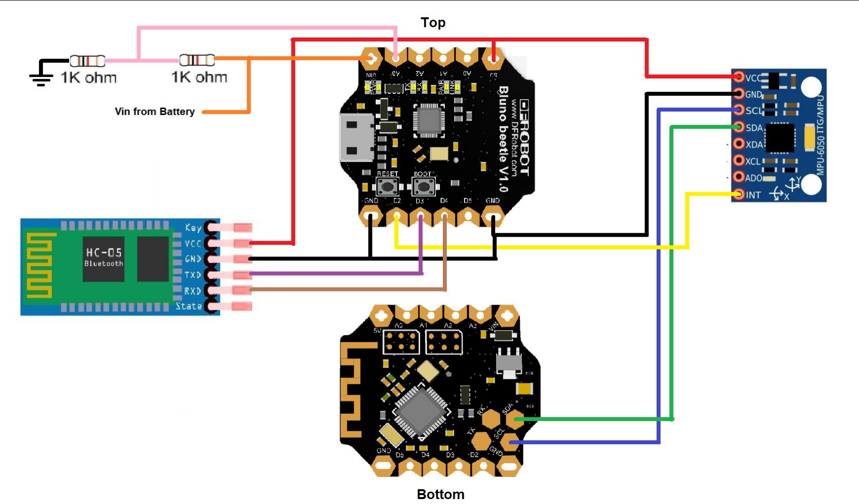
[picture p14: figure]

# Control System Gavin Dahl

## - MCU can currently send and receive data to/from a laptop via the Bluetooth module, but data can be out of sync

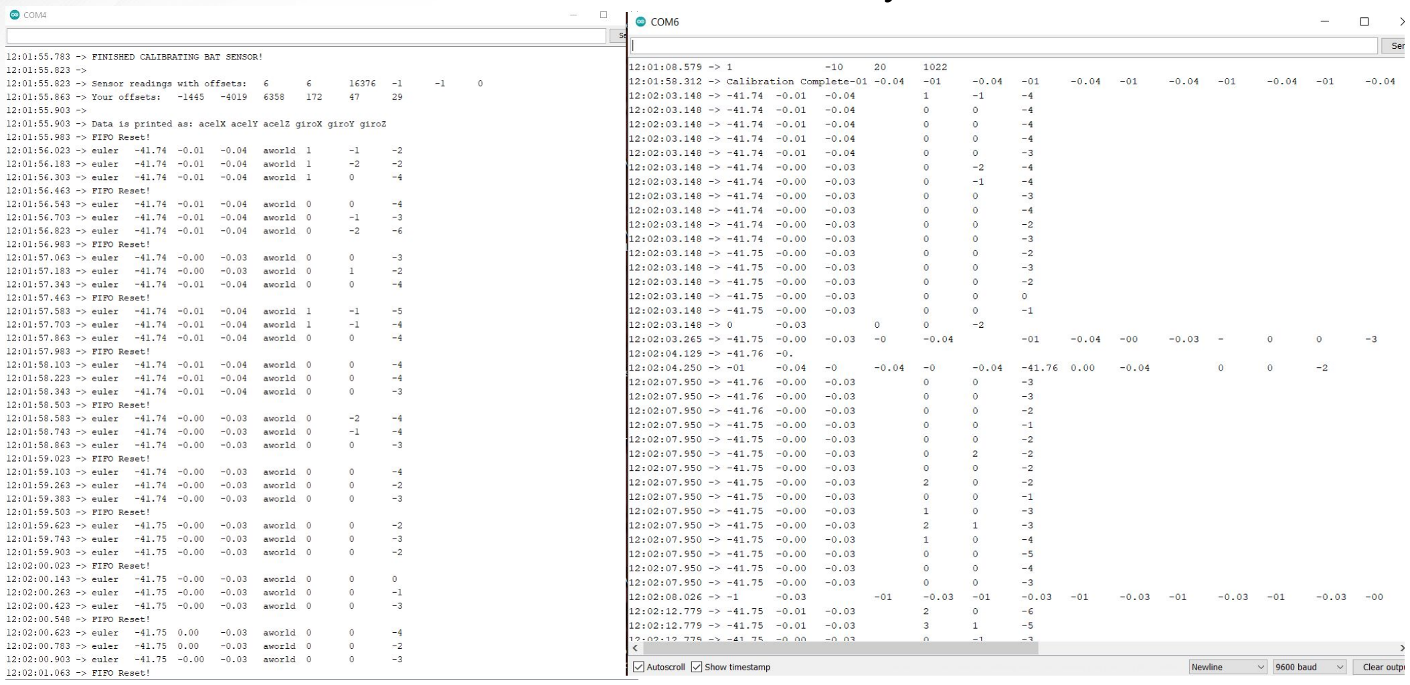
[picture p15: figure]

MCU Side | “App” Side

Android App | Pablo Barron
Accomplishments since last presentation: 4 Hrs | Ongoing progress/problems and plans until the next presentation
- Nothing has been completed since I have started integration with the MCU | ● Currently integrating with Control Subsystem and encountering some minor data sending issue ● App and Control subsystem should be fully integrated by the end of september

# Android App

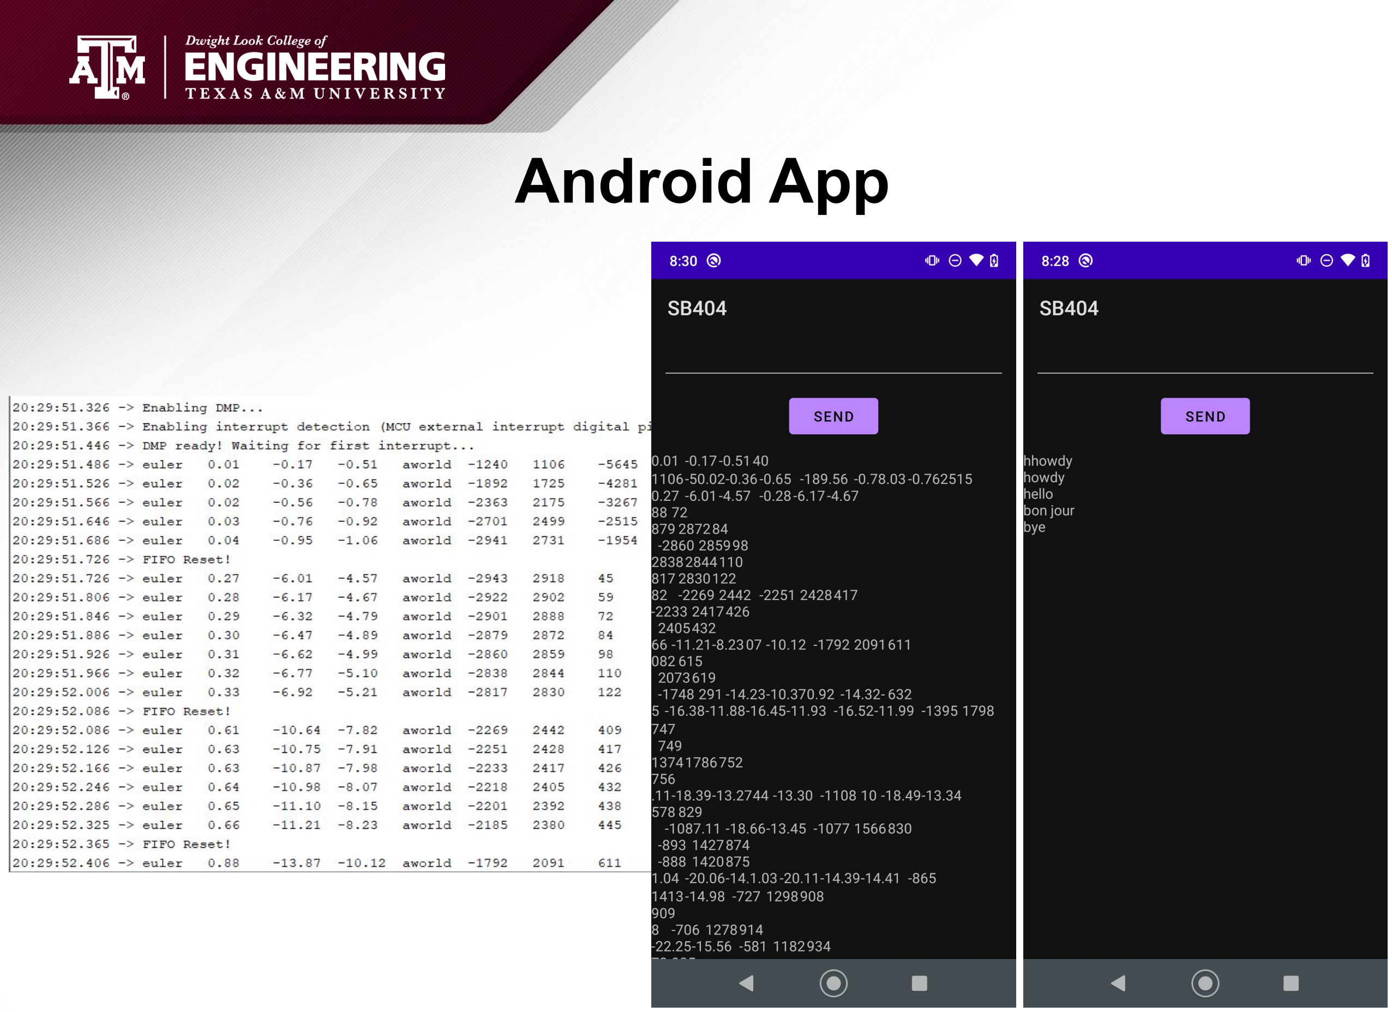
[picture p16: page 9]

# Power System

Accomplishments since 403 12 hr of effort | Ongoing progress/problems and plans until the next presentation
- Power and Control PCB designed and ordered. | ● Solder components onto a PCB

# Power System

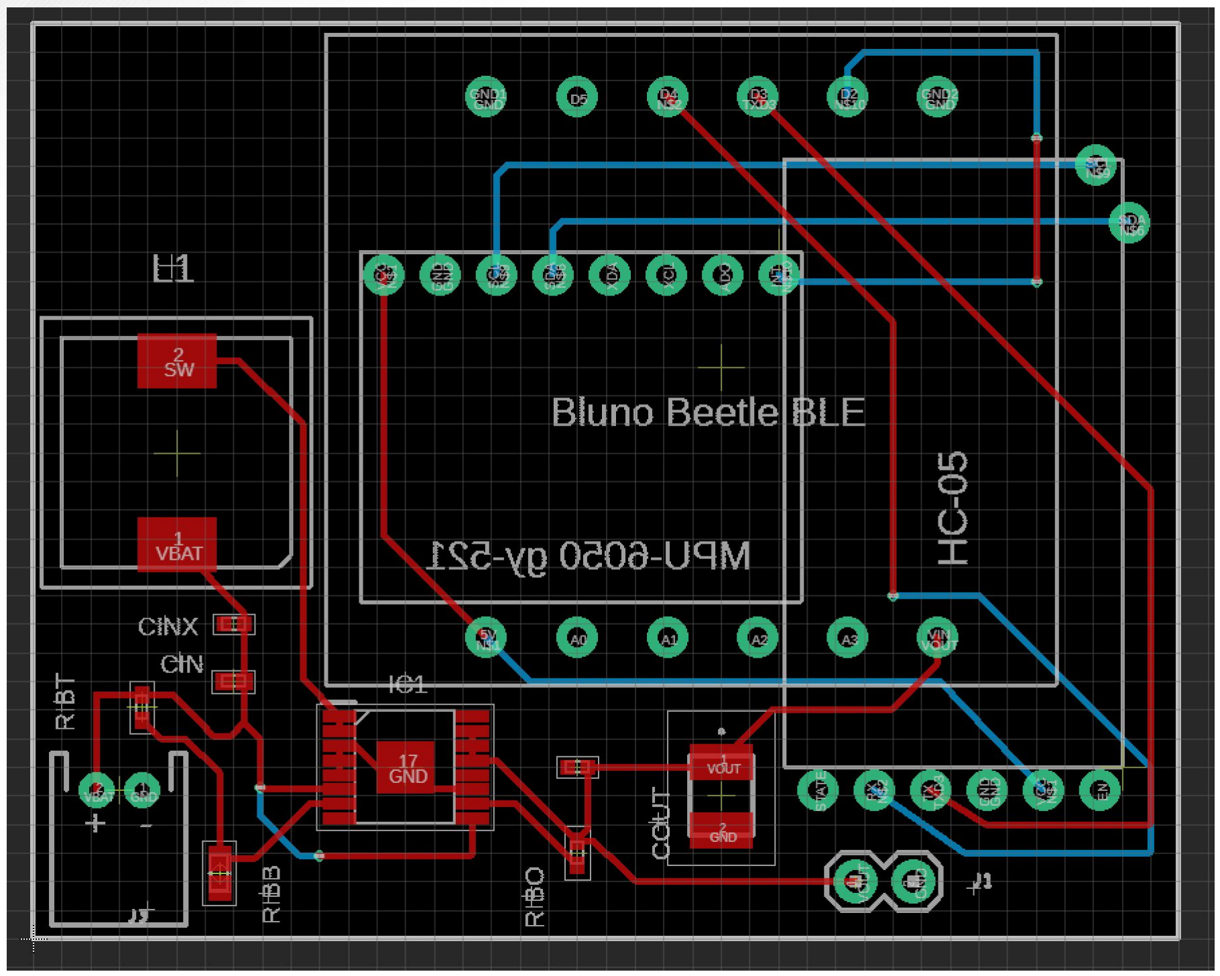
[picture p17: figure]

50.8x40.6 mm

# Machine Learning

# Plans until next presentation: - More data gathering to increase accuracy - ML integration with Android App

# Execution plan

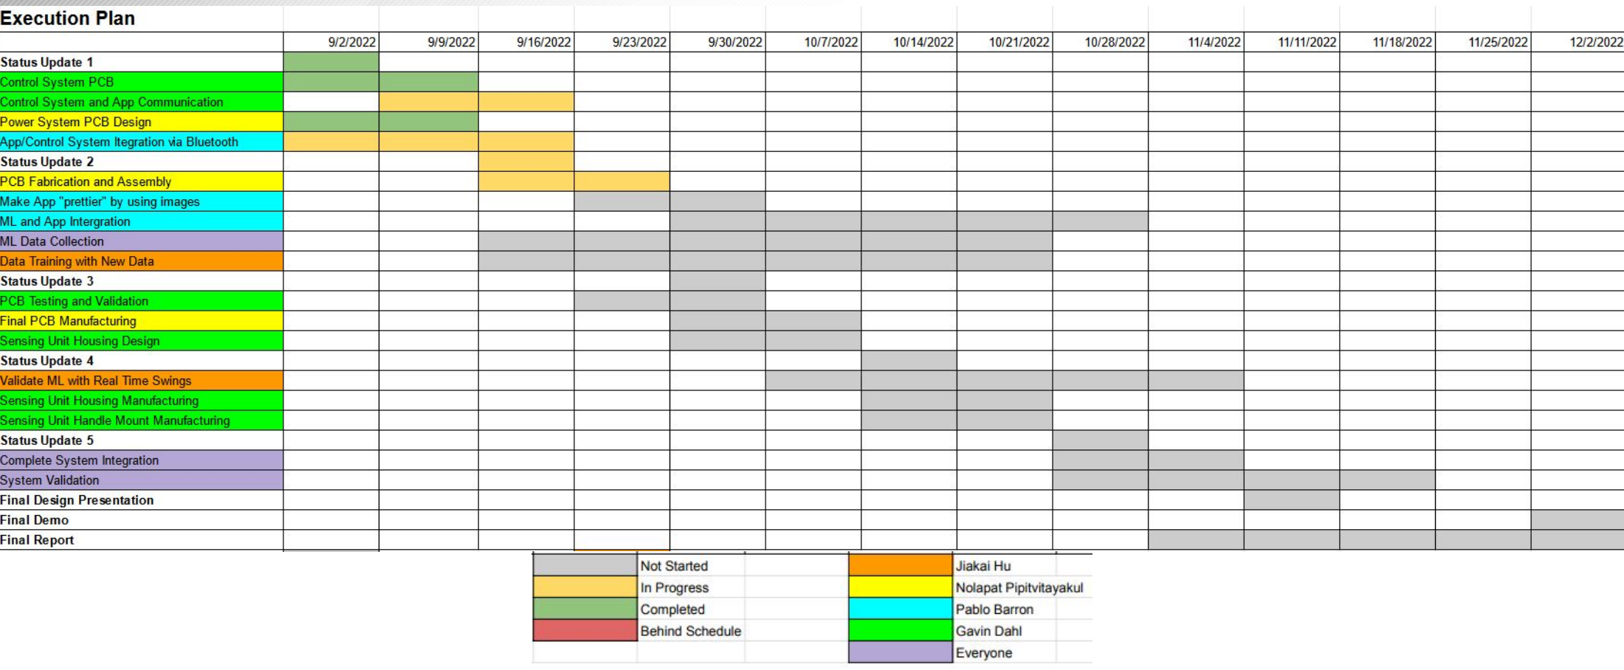
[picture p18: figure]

# Validation plan

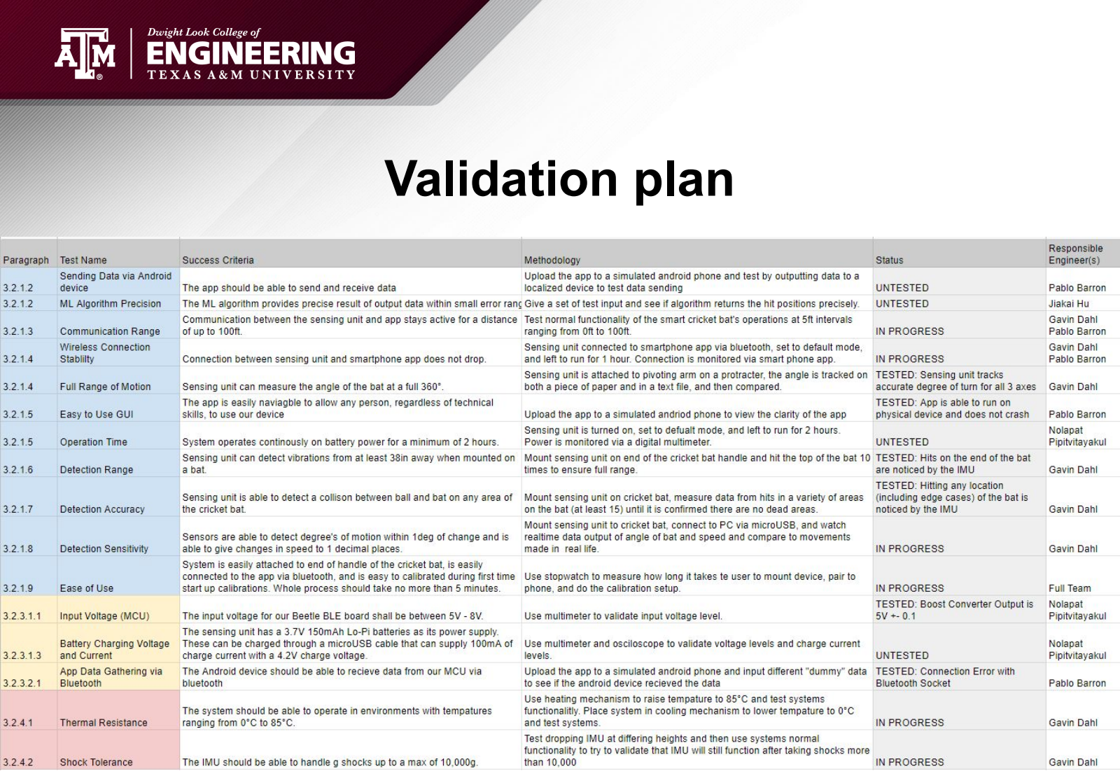
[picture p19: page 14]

# Parts Ordered

Part Description | Order Status
3 x Bluno Ble Microcontroller | Part Received
2 x HC-05 Bluetooth Module | Part Received
3 x gy-521 IMU | Part Received
1 x LiPo Battery 3.7V 150mah | Part Received
12 x Capacitor | Part Received
8 x Resistor | Part Received
3 x Inductor | Part Received
1 x Switching Voltage Regulators | Part Received
1 x JST Right-Angle Connector TH 2-Pin | Part Received

# Questions?

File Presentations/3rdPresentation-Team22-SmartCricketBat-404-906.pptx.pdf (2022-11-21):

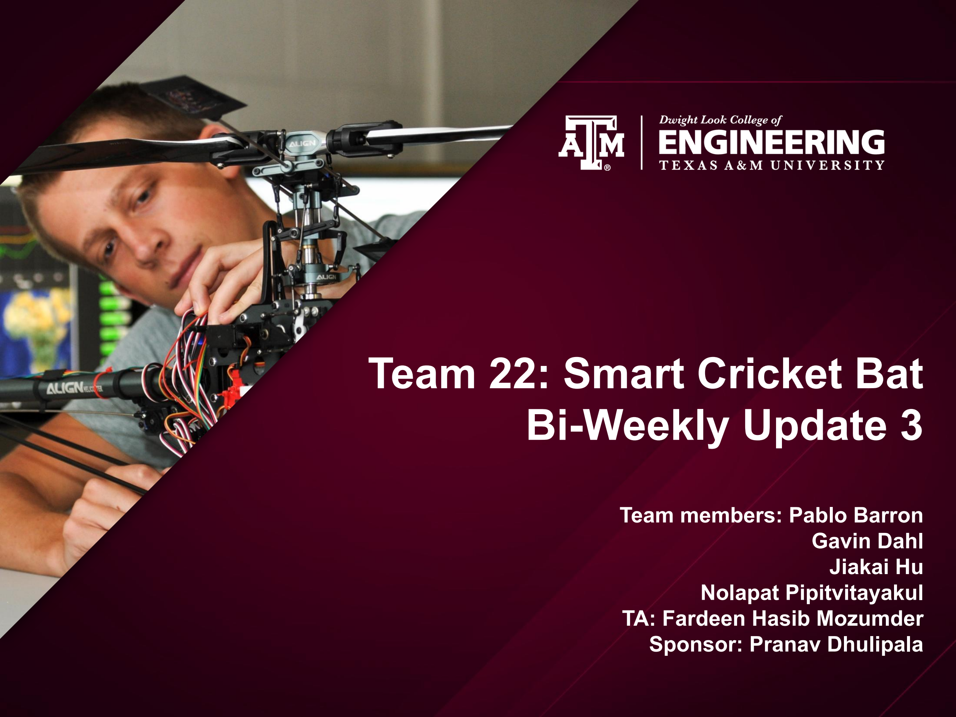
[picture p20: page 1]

# Team 22: Smart Cricket Bat Bi-Weekly Update 3

Team members: Pablo Barron Gavin Dahl
Jiakai Hu
Nolapat Pipitvitayakul
TA: Fardeen Hasib Mozumder Sponsor: Pranav Dhulipala

# Project description

## - Problem: “Cricket practice equipment lacks effectiveness without the assistance and guidance of a coach”

## - Solution proposal: “Create a device that will mount on the cricket bat and, through a user friendly app, gives real time feedback on the user’s cricket swing i.e. efficiency and swing angle. Must be easy to use and set up”


# Diagram of subsystems and interface

Rechargeable; Battery; User App; Interaction & Feedback; Machine Learning Algorithm; Microcontroller & Bluetooth; Accelerometer & Gyroscope; Battery Charger & Boost Converter; Bluetooth Connection; Power System; Control System; Commercial App; Graphical User Interface; Pablo Gavin Jiakai Nolapat; SCL & SDA Connection; Sensing Unit

Smart Cricket Bat

# Subsystem Overview

# - Android App: Will handle user interaction and

communication between the MCU and the ML algorithm.

The app receives data from the MCU via a bluetooth connection. The app will then send received data to ML algorithm to be processed - Power: Contains the boost-converter, on-board lithium battery power supply, and recharging station - ML Algorithm: Develop the ML algorithm for finding the specific characteristics of users swing - Control : A sensing unit that will communicate the IMU values from the swing to the user app through an MCU with bluetooth capabilities

# Project Timeline

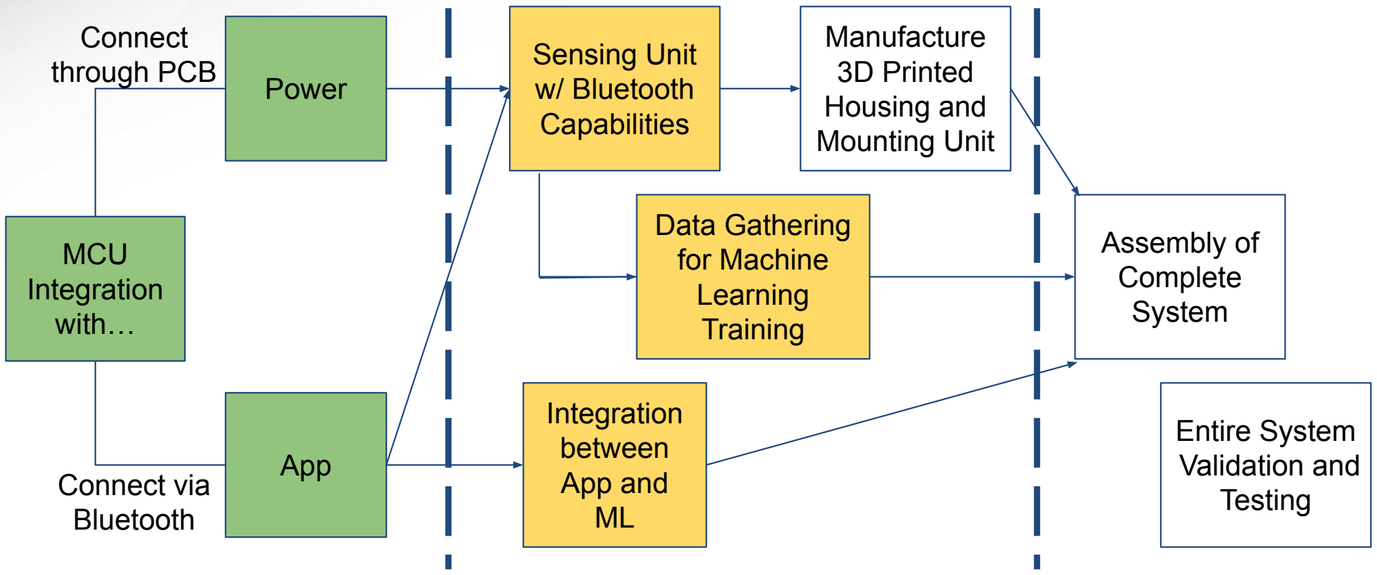
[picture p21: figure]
MCU Integration with…; Power; App Connect via; Bluetooth; Sensing Unit w/ Bluetooth Capabilities; Integration between App and ML; Data Gathering for Machine Learning Training; Entire System Validation and Testing; Assembly of Complete System; Manufacture 3D Printed Housing and Mounting Unit; Connect through PCB

9/2 - 9/30 | 9/30 - 10/28 | 10/28 - 12/2

Control System | Gavin Dahl
Accomplishments since last presentation 18 hr of effort | Ongoing progress/problems and plans until the next presentation
- MCU/App Integration ● Assembled control parts of PCB ● Basic tests performed to confirm it works as intended | ● PCB validation ● Housing Unit Design ● Start ML data collection

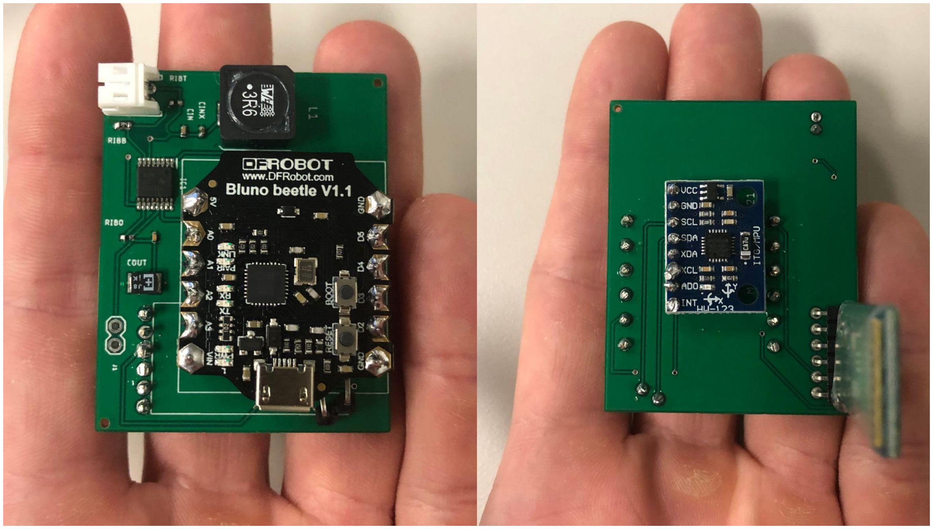
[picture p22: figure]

# Control System Gavin Dahl

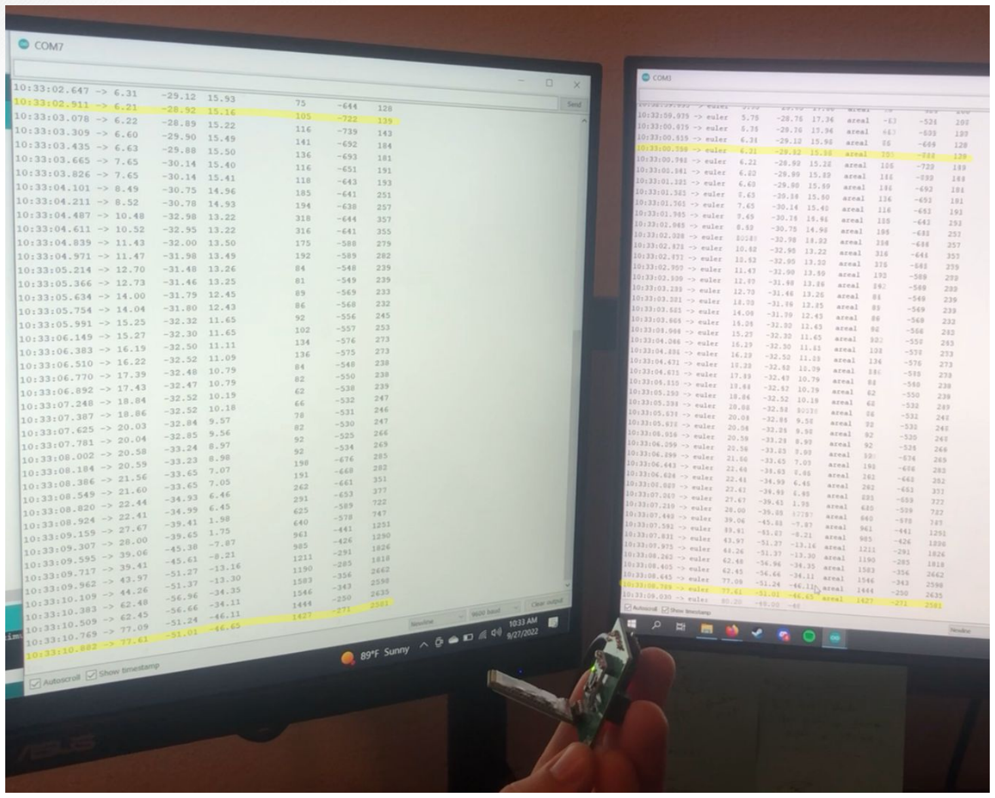
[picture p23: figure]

### - Left: Bluetooth - Right: MCU - ~2 sec delay in data transfer - No gaps or inconsistencies in data

Android App | Pablo Barron
Accomplishments since last presentation: 4 Hrs | Ongoing progress/problems and plans until the next presentation
- Have completed the app integration with the control subsystem. Proper data sending connection has been established. | ● Will now begin validating connectivity and data sending ● Currently integrating with ML, but encountering difficulty due to Android Studio only liking TensorFlow Models

# Android App

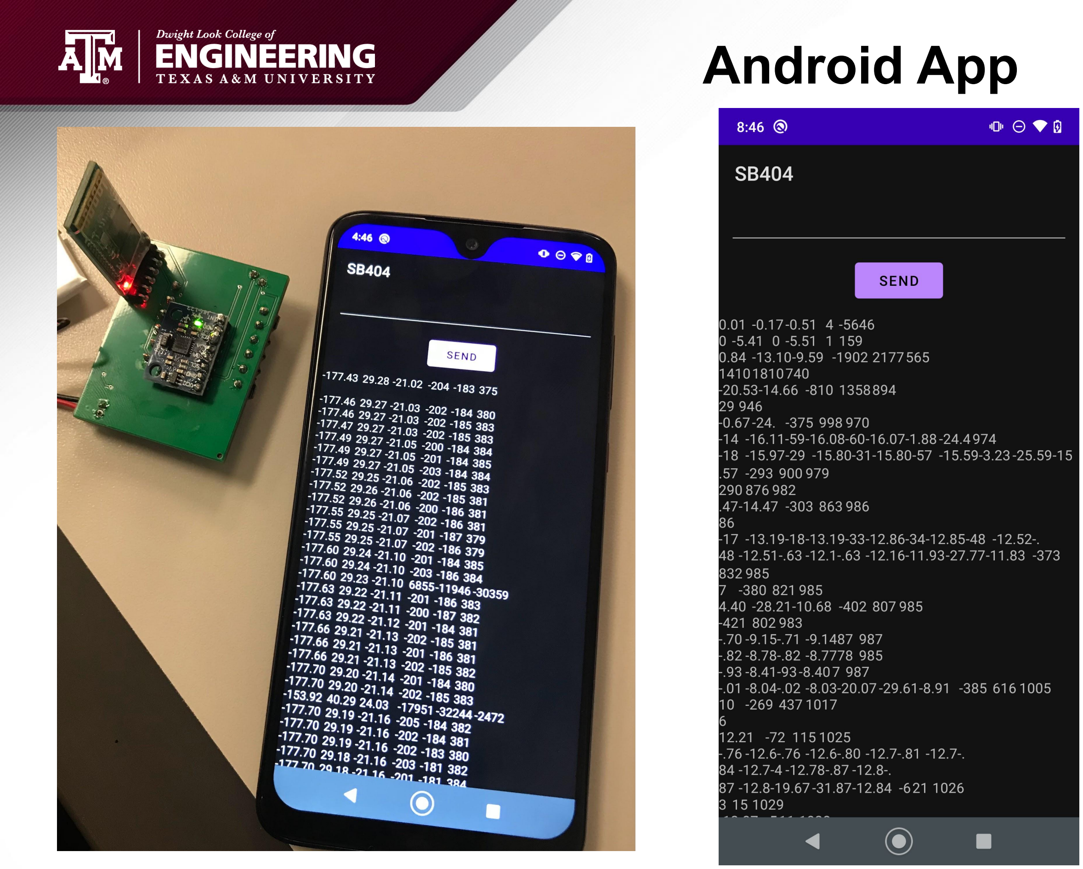
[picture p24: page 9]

# Power System

Accomplishments since 403 12 hr of effort | Ongoing progress/problems and plans until the next presentation
- Assembled power parts of PCB ● Power/Control integration ● Able to power the MCU, IMU, and Bluetooth from the battery and collect data | ● Add battery charging circuit to the PCB design ● Order final PCB

# Power System

50.8x40.6 mm

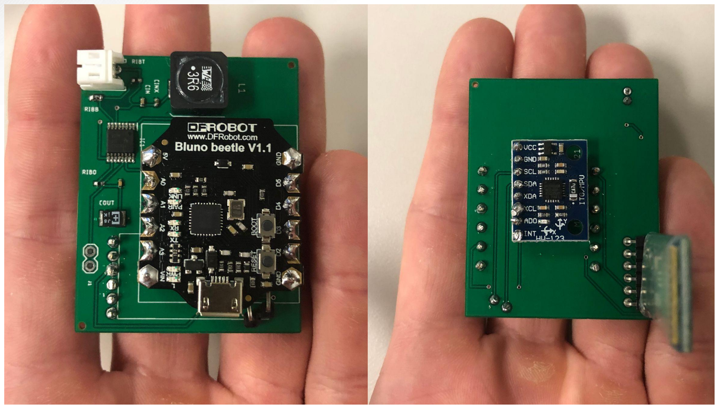
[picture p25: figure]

# Machine Learning

# Accomplishments since last presentation: - Transforming the .sav file to .tflite or Scikit-Learn Random Forest Model to be used by Android App Plans until next presentation: - More data gathering to increase accuracy

# Execution plan


# Validation plan


# Parts Ordered

Part Description | Order Status
3 x Bluno Ble Microcontroller | Part Received
2 x HC-05 Bluetooth Module | Part Received
3 x gy-521 IMU | Part Received
1 x LiPo Battery 3.7V 150mah | Part Received
12 x Capacitor | Part Received
8 x Resistor | Part Received
3 x Inductor | Part Received
1 x Switching Voltage Regulators | Part Received
1 x JST Right-Angle Connector TH 2-Pin | Part Received

# Questions?

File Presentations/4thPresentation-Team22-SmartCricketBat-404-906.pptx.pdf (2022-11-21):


# Team 22: Smart Cricket Bat Bi-Weekly Update 4

Team members: Pablo Barron Gavin Dahl
Jiakai Hu
Nolapat Pipitvitayakul
TA: Fardeen Hasib Mozumder Sponsor: Pranav Dhulipala

# Project description

## - Problem: “Cricket practice equipment lacks effectiveness without the assistance and guidance of a coach”

## - Solution proposal: “Create a device that will mount on the cricket bat and, through a user friendly app, gives real time feedback on the user’s cricket swing i.e. efficiency and swing angle. Must be easy to use and set up”


# Diagram of subsystems and interface

Rechargeable; Battery; User App; Interaction & Feedback; Machine Learning Algorithm; Microcontroller & Bluetooth; Accelerometer & Gyroscope; Battery Charger & Boost Converter; Bluetooth Connection; Power System; Control System; Commercial App; Graphical User Interface; Pablo Gavin Jiakai Nolapat; SCL & SDA Connection; Sensing Unit

Smart Cricket Bat

# Subsystem Overview

# - Android App: Will handle user interaction and

communication between the MCU and the ML algorithm.

The app receives data from the MCU via a bluetooth connection. The app will then send received data to ML algorithm to be processed - Power: Contains the boost-converter, on-board lithium battery power supply, and recharging station - ML Algorithm: Develop the ML algorithm for finding the specific characteristics of users swing - Control : A sensing unit that will communicate the IMU values from the swing to the user app through an MCU with bluetooth capabilities

# Project Timeline

MCU Integration with…; Power; App Connect via; Bluetooth; Sensing Unit w/ Bluetooth Capabilities; Integration between App and ML; Data Gathering for Machine Learning Training; Entire System Validation and Testing; Assembly of Complete System; Manufacture 3D Printed Housing and Mounting Unit; Connect through PCB

9/2 - 9/30 | 9/30 - 10/28 | 10/28 - 12/2

# Control System Gavin Dahl


Accomplishments since last presentation 20 hr of effort | Ongoing progress/problems and plans until the next presentation
- Housing and Mounting Unit Designed | ● Finish final PCB assembly and validation ● Housing and Mounting Unit Printing ● ML data collection

# Control System Gavin Dahl


# Control System Gavin Dahl


- Calculated Expected
Acceleration at Impact:
31.16 g’s
- Measured Acceleration at Impact:
32.883 g’s

# Power System

Accomplishments since 403 12 hr of effort | Ongoing progress/problems and plans until the next presentation
- Designed battery charging circuit ● Received final PCB | ● Assemble final PCB ● Testing the final PCB ● Help with ML data collection

# Power System


45.7x45.7 mm

# Power System


Android App | Pablo Barron

## Accomplishments since last presentation: 16 Hrs

## Ongoing progress/problems and plans until the next presentation

## - No accomplishments still working on implementation of

ML

- Currently integrating with ML,

## but encountering difficulty due to Android Studio only liking TensorFlow Models - Tried Tensor Flow (.tflite and .pb) and skLearn (.sav and .h5) but encountered Converter errors - Currently Switched to ONNX Model (.ort) using onnxruntime

# Android App


# Android App


# Machine Learning

# Accomplishments since last presentation: - Transforming the Scikit-Learn Random Forest Model to .ort then.onnx file to be used by Android App Plans until next presentation: - More data gathering to increase accuracy


## Errors when Converting sklearn model with all kinds of file type to


## .tflite

## Errors when Converting tensorflow model with all kinds of file type to .tflite


# Execution plan


# Validation plan


# Parts Ordered

Part Description | Order Status
3 x Bluno Ble Microcontroller | Part Received
2 x HC-05 Bluetooth Module | Part Received
3 x gy-521 IMU | Part Received
1 x LiPo Battery 3.7V 150mah | Part Received
12 x Capacitor | Part Received
8 x Resistor | Part Received
3 x Inductor | Part Received
1 x Switching Voltage Regulators | Part Received
1 x JST Right-Angle Connector TH 2-Pin | Part Received

# Questions?

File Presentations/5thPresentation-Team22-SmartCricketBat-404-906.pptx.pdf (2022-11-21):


# Team 22: Smart Cricket Bat Bi-Weekly Update 5

Team members: Pablo Barron Gavin Dahl
Jiakai Hu
Nolapat Pipitvitayakul
TA: Fardeen Hasib Mozumder Sponsor: Pranav Dhulipala

# Project description

## - Problem: “Cricket practice equipment lacks effectiveness without the assistance and guidance of a coach”

## - Solution proposal: “Create a device that will mount on the cricket bat and, through a user friendly app, gives real time feedback on the user’s cricket swing i.e. efficiency and swing angle. Must be easy to use and set up”


# Diagram of subsystems and interface

Rechargeable; Battery; User App; Interaction & Feedback; Machine Learning Algorithm; Microcontroller & Bluetooth; Accelerometer & Gyroscope; Battery Charger & Boost Converter; Bluetooth Connection; Power System; Control System; Commercial App; Graphical User Interface; Pablo Gavin Jiakai Nolapat; SCL & SDA Connection; Sensing Unit

Smart Cricket Bat

# Project Timeline

MCU Integration with…; Power; App Connect via; Bluetooth; Sensing Unit w/ Bluetooth Capabilities; Integration between App and ML; Data Gathering for Machine Learning Training; Entire System Validation and Testing; Assembly of Complete System; Manufacture 3D Printed Housing and Mounting Unit; Connect through PCB

9/2 - 9/30 | 9/30 - 10/28 | 10/28 - 12/2

# Power System

Accomplishments since last presentation 10 hr of effort | Ongoing progress/problems and plans until the next presentation
- Finished assemble final PCB ● Tested the battery charging circuit | ● ML data collection

# Power System


Charge current: 150 mA
Charge voltage: 4.2 V

Control System | Gavin Dahl
Accomplishments since last presentation 18 hr of effort | Ongoing progress/problems and plans until the next presentation
- Housing and Mounting Unit printed, designs changed as needed, Final Design printed ● Bluetooth Range Validated | ● Finish final PCB assembly and re-validation ● ML data collection ● Try to “polish” bluetooth


# Control System Gavin Dahl

Charging Port; Bluetooth Module; MCU

Boost Converter +
Battery and Switch

*IMU on bottom layer/side of PCB

# Control System Gavin Dahl


Bluetooth Validation
- Wrote sketch for MCU to send current distance, incremented by 10ft, when prompted by bluetooth-connected device
- Connection stable and able to send data until 220 to 240 ft

Sensing Unit Mass Verification
- Took average mass from 10 weigh-ins:
| 85.89 ± 0.01 grams
(a) Bluetooth Distance Validation
(b) Housing Unit + PCB + Battery Total Mass

# Control System Gavin Dahl


- Calculated Expected
Acceleration at Impact:
139.4 g’s
- Measured Acceleration at Impact:
114.188 g’s

Android App | Pablo Barron
Accomplishments and changes since last presentation: 13 Hrs | Ongoing progress/problems and plans until the next presentation
- Validated Range of Bluetooth with Gavin: 240 ft ● Switched ML to run on the cloud instead of locally: Firebase | ● Currently still integrating with ML and creating Firebase server to host pre-processing and ML

# Android App


# Machine Learning

# Accomplishments since last presentation: - Preprocessed and trained newly gathered data Plans until next presentation: - More data gathering to increase accuracy

# Pairplot


# Heatmap, feature importance, and result


# Execution plan


# Validation plan


# Parts List

Part Description | Order Status
3 x Bluno Ble Microcontroller | Part Received
2 x HC-05 Bluetooth Module | Part Received
3 x gy-521 IMU | Part Received
1 x LiPo Battery 3.7V 150mah | Part Received
12 x Capacitor | Part Received
8 x Resistor | Part Received
3 x Inductor | Part Received
1 x Switching Voltage Regulators | Part Received
1 x JST Right-Angle Connector TH 2-Pin | Part Received

# Questions?

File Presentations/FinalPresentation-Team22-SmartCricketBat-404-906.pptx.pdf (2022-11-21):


# Team 22: Smart Cricket Bat Final Presentation

Team members: Pablo Barron Gavin Dahl
Jiakai Hu
Nolapat Pipitvitayakul
TA: Fardeen Hasib Mozumder Sponsor: Pranav Dhulipala

# Project description

## - Problem: “Cricket practice equipment lacks effectiveness without the assistance and guidance of a coach”

## - Solution proposal: “Create a device that will mount on the cricket bat and, through a user friendly app, gives real time feedback on the user’s cricket swing i.e. efficiency and swing angle. Must be easy to use and set up”


# Diagram of Subsystems and Interface

Rechargeable; Battery; User App; Interaction & Feedback; Machine Learning Algorithm; Microcontroller & Bluetooth; Accelerometer & Gyroscope; Battery Charger & Boost Converter; Bluetooth Connection; Power System; Control System; Commercial App; Graphical User Interface; Pablo Gavin Jiakai Nolapat; SCL & SDA Connection; Sensing Unit

Smart Cricket Bat

# Picture of System


# Power System

bluetooth • LiPo battery as a power source; Boost Converter; Charging Circuit; LiPo Battery; Control System; Power System

# - Distribute proper power requirements to MCU, IMU, and

# - Boost battery voltage with boost converter - Charging circuit to charge the battery

# Power System


| Min | Nominal | Max
Battery Voltage (V) | 3 | 3.7 | 4.2
Current Draw (mA) | 101 | 123 | 158
Voltage Output (V) | 4.975 | 4.976 | 4.988

## - Boost the LiPo battery voltage with 5V dc-dc boost converter

## - Battery charging circuit with 4.2V charging voltage and 150mA charging current

# Control System Gavin Dahl

Charging Port; Bluetooth Module; Overview; MCU; PCB Specs; ● Mass: ○ 21.47 ± 0.01 g ● Dimensions: ○ 47.5 mm x 47.5 mm

● Microcontroller:
ATmega328P
● Bluetooth Module: HC-05
● IMU: MPU-6050

Boost Converter +
Battery and Switch

*IMU on bottom layer/side of PCB

# Control System Gavin Dahl

# Housing Unit Specifications

Actual | Sponsor Specifications
Dimensions (d x h) | 69mm x 38mm | 60mm x 35mm
Mass | 55.74 ± 0.01 g | less than 100g


# Control System


Height of Drop | Calculated Impact (g) | Actual Impact (g)
1ft | 31.16 | 32.883
10ft | 98.534 | 87.95
20ft | 139.4 | 114.188

# Control System


Axis | Measured Range of Degree | Average Peak-to-Peak Variation
X | 5° to -92° | ~0.1°
Y | -5° to 83° | ~1.67°
Z | 5° to -81° | ~14.32°

# Control System Gavin Dahl

Bluetooth Validation
- Wrote sketch for MCU to send current distance, incremented by 10ft, when prompted by bluetooth-connected device
- Connection stable and able to send data until 220 to 240 ft (~67 to 73m)
- Sponsor Specification - 165 ft (~50m)

Sensing Unit Mass Verification
- Took average mass from 10 weigh-ins: 88.27 ± 0.01 grams


(a) Bluetooth Distance Validation


(b) Housing Unit + PCB + Battery Total Mass


Android App Pablo Barron

# Bluetooth Data Sending and Range Validation


# Bluetooth Range: 220ft - 240ft

Time | Gyro: XYZ | Acce: XYZ

Android App and ML Sending | Pablo Barron

# Problems Faced:

## - Switched from running locally to having to run ML Code on a cloud server - Firebase did not accept our ML model, constant conversion errors when converting to TensorFlow - Currently working with AWS ec2 and s3 with AWS Amplify


## Transferring model to aws server

## ML integration


## Results on aws server are the same with google colab

# Results


Random Forest | KNN
Logistic Regression | SVM

Decision Tree

# Heatmap and feature importance


# Conclusion

# Changes from 403 Documents

## - ML will run on a cloud server instead of running locally on device - Bluetooth changed from BLE to Classic Bluetooth

# Tasks to Complete Before Demo

## - Finish ML and App integration ~ 1 week - Collect more data to increases ML accuracy - Validate ML and App Communication and test completed system

# Questions?

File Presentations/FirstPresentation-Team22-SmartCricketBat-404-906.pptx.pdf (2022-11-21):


## Team 22: Smart Cricket Bat

Team members: Pablo Barron Gavin Dahl
Jiakai Hu
Nolapat Pipitvitayakul
TA: Fardeen Hasib Mozumder Sponsor: Pranav Dhulipala

## Project description

- Problem: “Cricket practice equipment lacks effectiveness without the assistance and guidance of a coach”
- Solution proposal: “Create a device that will mount on the cricket bat and, through a user friendly app, gives real time feedback on the user’s cricket swing i.e. efficiency and swing angle. Must be easy to use and set up”


## Diagram of subsystems and interface

Rechargeable; Battery; User App; Interaction & Feedback; Machine Learning Algorithm; Microcontroller & Bluetooth; Accelerometer & Gyroscope; Battery Charger & Boost Converter; Bluetooth Connection; Power System; Control System; Commercial App; Graphical User Interface; Pablo Gavin Jiakai Nolapat; SCL & SDA Connection; Sensing Unit; Internet Connection

Smart Cricket Bat

## Subsystem Overview

- Android App: Will handle user interaction and communication between the MCU and the ML algorithm. The app receives data from the MCU via a bluetooth connection. The app will then send received data to ML algorithm to be processed
- Power: Contains the boost-converter, on-board lithium battery power supply, and recharging station
- ML Algorithm: Develop the ML algorithm for finding the specific characteristics of users swing
- Control : A sensing unit that will communicate the IMU values from the swing to the user app through an MCU with bluetooth capabilities

## Major Changes For 404

- Switching from Low-Energy Bluetooth 4.0 to Standard Bluetooth 3.0
- App language changed from Java to Kotlin due to lack of updated reference/source videos.

## Project Timeline

MCU Integration with…; Power; App; Connect through PCB; Connect via Bluetooth; Sensing Unit w/ Bluetooth Capabilities; Integration between App and ML; Data Gathering for Machine Learning Training; Entire System Validation and Testing; Assembly of Complete System

9/2 - 9/30 | 9/30 - 10/28 | 10/28 - 12/2

Control System | Gavin Dahl
Accomplishments since 403 1 hr of effort | Ongoing progress/problems and plans until the next presentation
- Confirmed MCU and IMU communication is still working as intended | ● Integration with power system and finalization of combined PCB design ● Integration between MCU and App through new bluetooth module

## Control System Gavin Dahl


- Microcontroller: ATmega328P
- Bluetooth Module: HC-05
- Inertial Measurement Unit: MPU-6050

## Android App


- Accomplishments since
403: 8 Hrs
– Have established a
stable bluetooth
connection to
received data from
MCU
- Ongoing Progress:
– Fully integrate app
with Control
Subsystem
– Make app “prettier”
– ML and app
integration

## Android App


## Power System

Accomplishments since 403 1 hr of effort | Ongoing progress/problems and plans until the next presentation
- Confirmed boost converter circuit on perfboard is still working | ● Design PCB for boost converter circuit ● Integration with control system and finalization of combined PCB design

## Power System

- 5V DC-DC Boost Converter Circuit
- 3.7V 150mAh LiPo Battery
- LiPo Battery Charger



## Machine Learning

Achieved in 403:
- Subsystem completed, get around 13% accuracy
Ongoing process:
- Data gathering to increase accuracy
- ML integration with Android App

## Machine Learning


- Chunking over time period
- PSD and FFT and each period
- Take peaks
- Separate data
70% for training
30% for testing
- recognize each hit to each area

## Machine Learning


## Execution plan


## Validation plan


## Parts Ordered

Part Description | Order Status
3 x Bluno Ble Microcontroller | Order Placed
3 x HC-05 Bluetooth Module | Awaiting Order Placement
3 x gy-521 IMU | Awaiting Order Placement

## Questions?

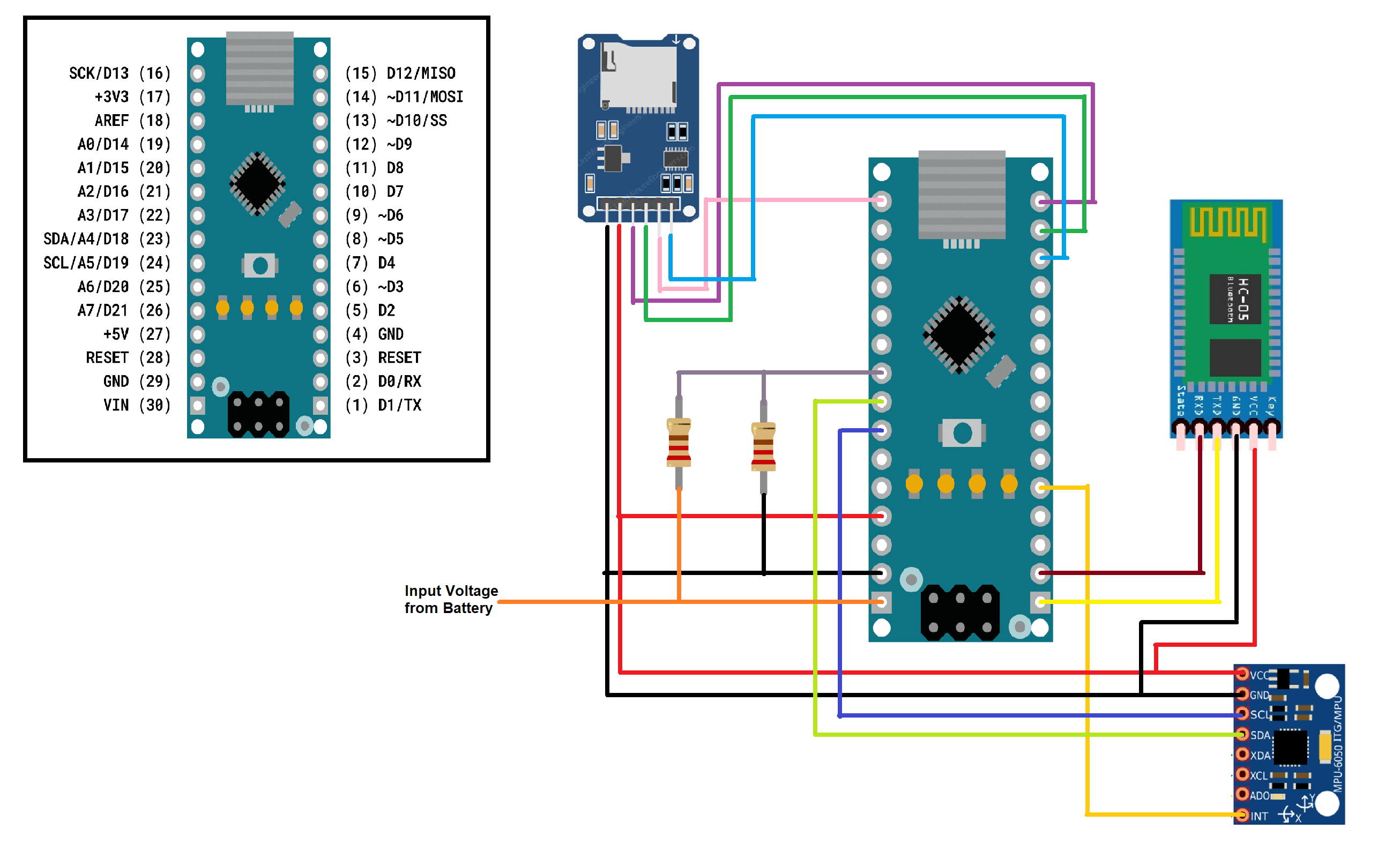
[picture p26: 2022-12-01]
MCU Design/ImprovedMCU/ImprovedMCUWMicroSD_TopLevelSchematic.png

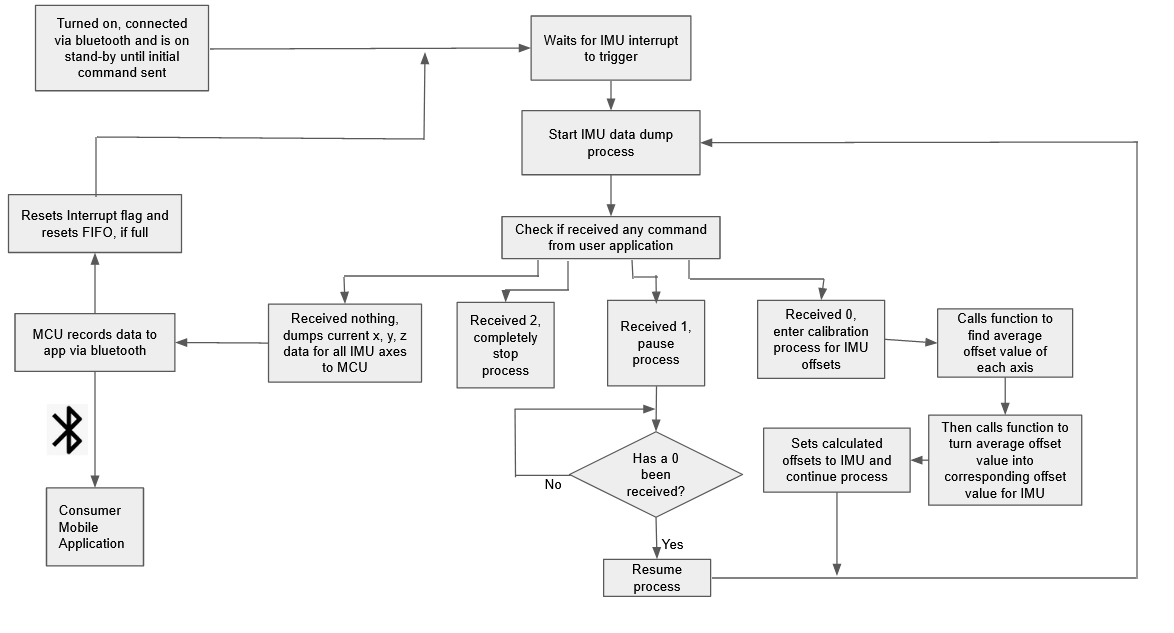
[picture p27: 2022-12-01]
MCU Design/ArdunioCodeFlowchart.PNG

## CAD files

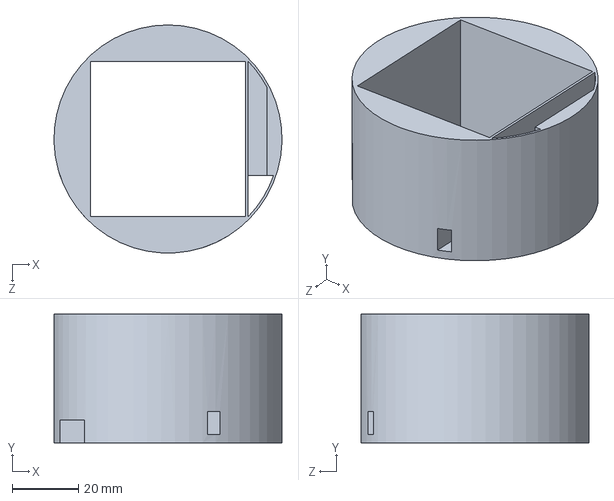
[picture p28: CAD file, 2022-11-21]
Housing Unit/FINALHousingUnitCOPYCOPY.SLDPRT
69.0 x 39.0 x 69.0 mm

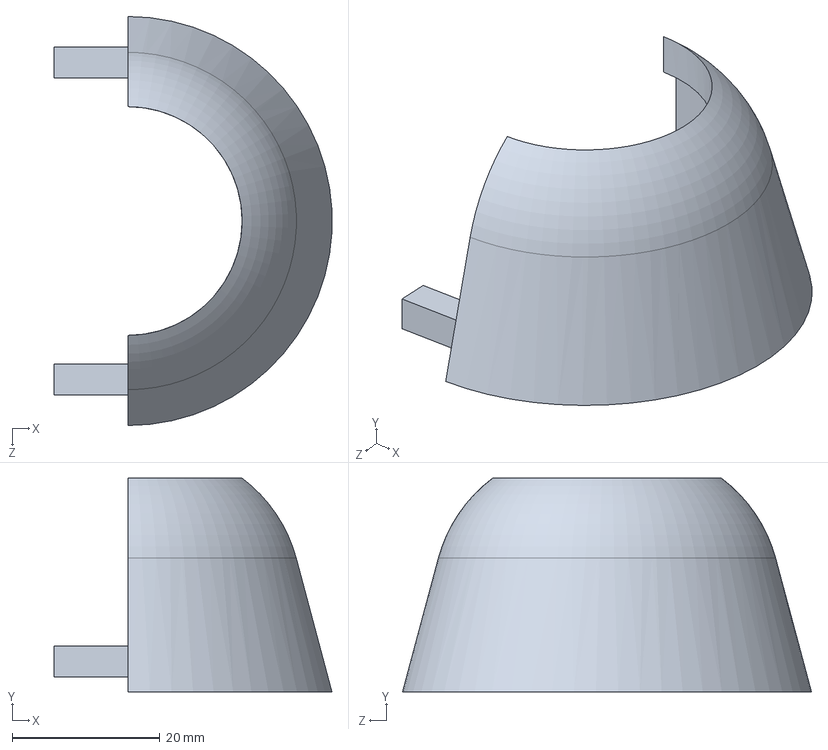
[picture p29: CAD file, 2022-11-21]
Housing Unit/HousingUnitConnectorFINAL.SLDPRT
37.7 x 29.0 x 55.5 mm

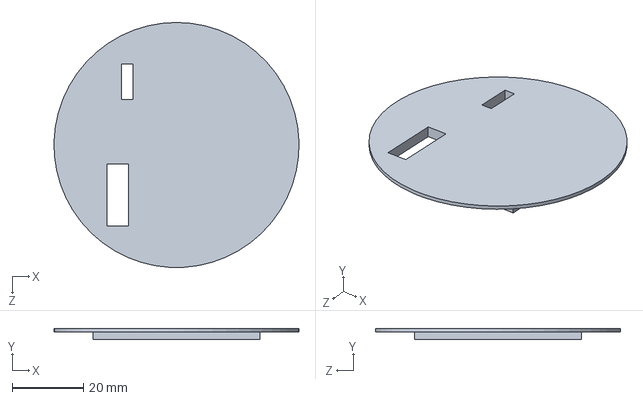
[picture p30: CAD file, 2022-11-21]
Housing Unit/FINALHousingUnitLid.SLDPRT
69.0 x 3.00 x 69.0 mm

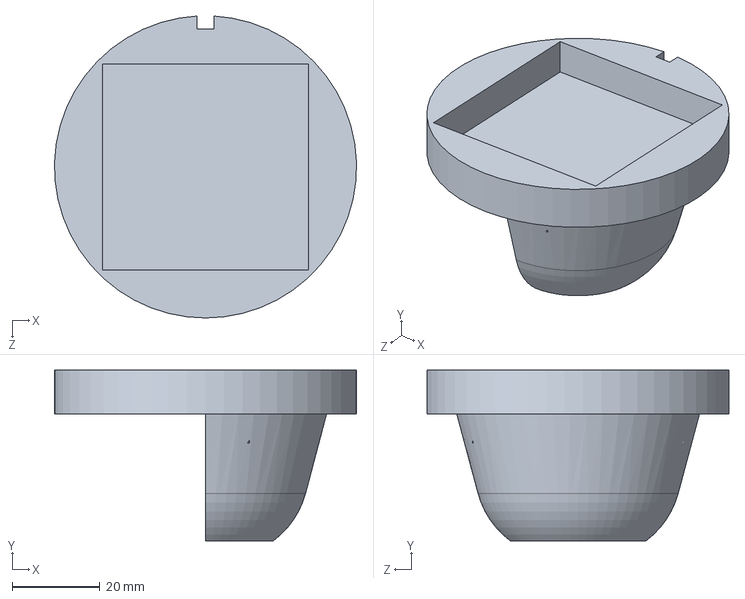
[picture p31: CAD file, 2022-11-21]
Housing Unit/MountingUnitFINAL.SLDPRT
69.0 x 39.0 x 68.9 mm

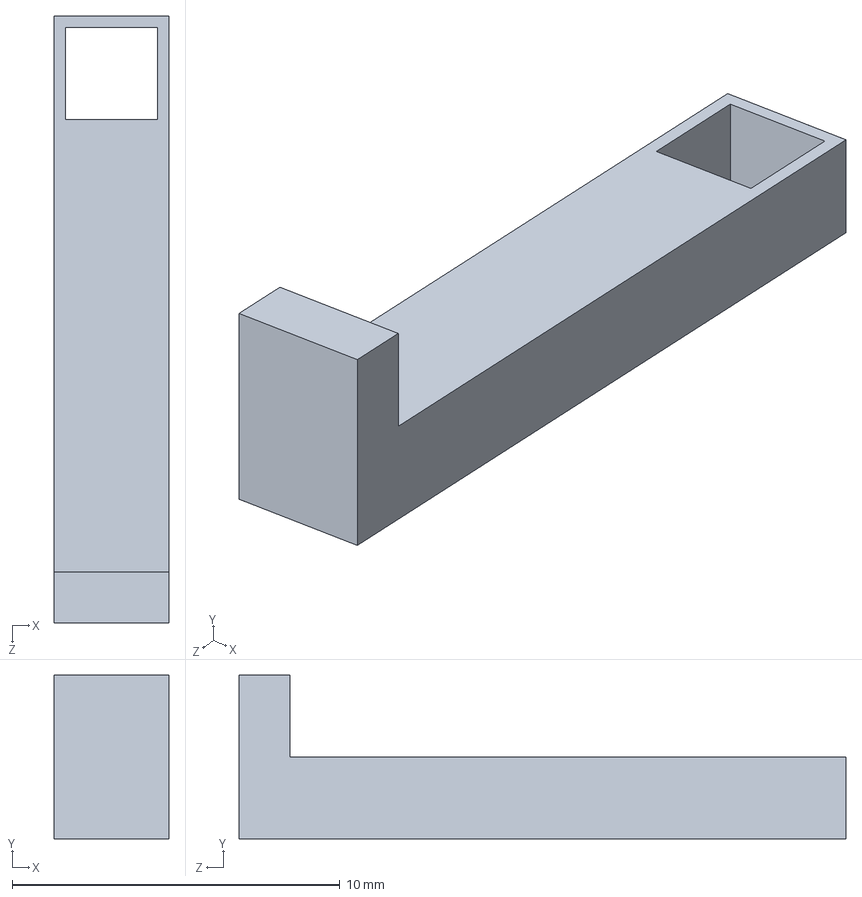
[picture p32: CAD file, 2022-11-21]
Housing Unit/ONOFFSwitch.SLDPRT
3.50 x 5.00 x 18.5 mm

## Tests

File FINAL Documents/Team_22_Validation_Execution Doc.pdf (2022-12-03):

# Smart Cricket Bat

## Gavin Dahl, Jiakai Hu, Pablo Barron, Nolapat Pipitvitayakul

# EXECUTION PLAN

## Execution Plan for the Smart Cricket Bat

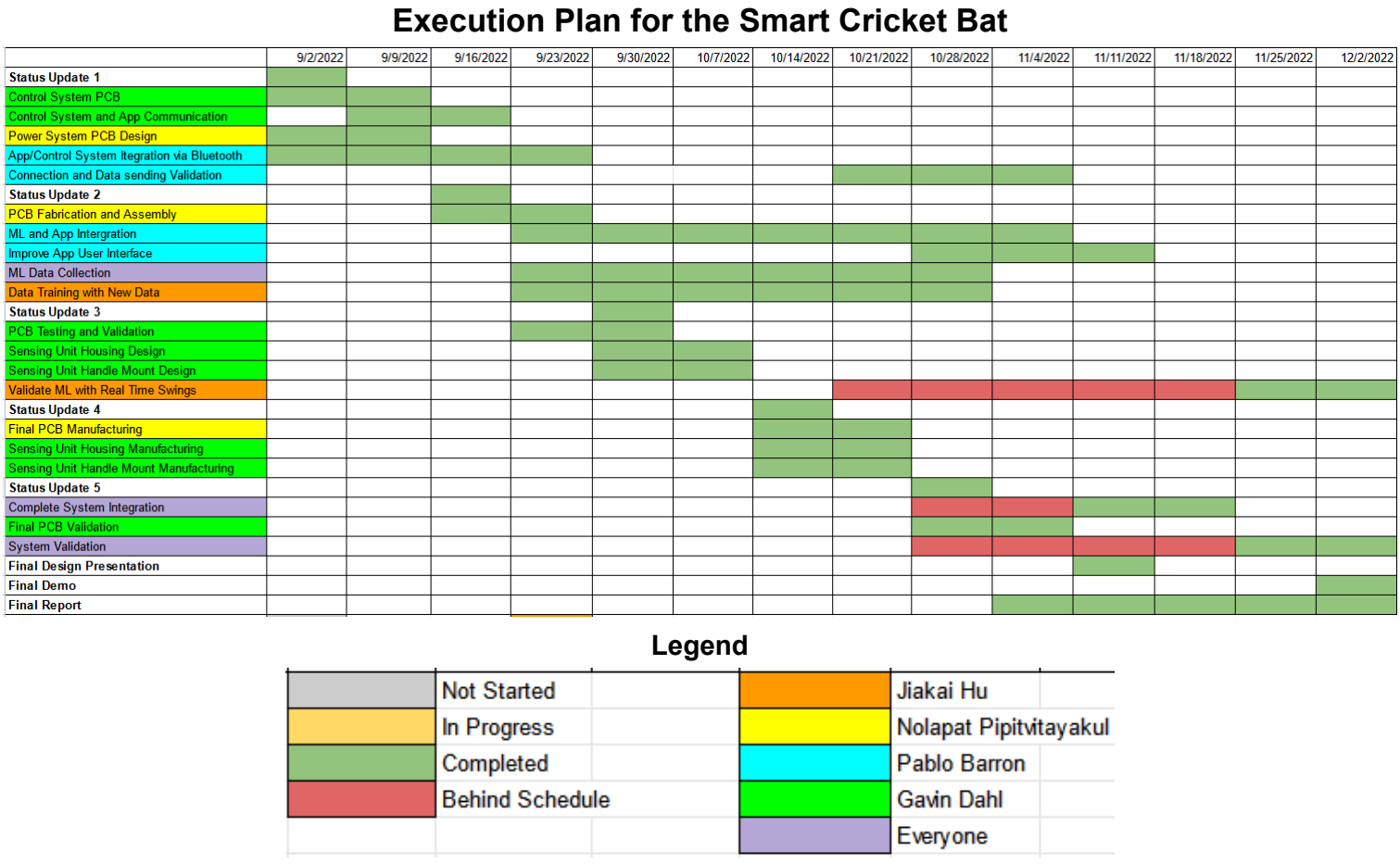
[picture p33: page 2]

### Legend

# Smart Cricket Bat

## Gavin Dahl, Jiakai Hu, Pablo Barron, Nolapat Pipitvitayakul

# VALIDATION PLAN

## Validation Plan for the Smart Cricket Bat

Paragrap h | Test Name | Success Criteria | Methodology | Status | Responsible Engineer(s)
3.2.1.2 | Sending Data via Android device | The app should be able to send data (input for ML Algorithm) | Upload the app to a simulated android phone and test by outputting data to a localized device to test data sending | TESTED: App is able to send real time data to a device via an input stream | Pablo Barron
3.2.1.2 | ML Algorithm Precision | The ML algorithm provides precise results of output data within acceptable error range. | Use all data gathered to test the training and testing accuracy. | TESTED: Training accuracy around 98% and Testing accuracy around 23% | Jiakai Hu
3.2.1.3 | Communication Range | Communication between the sensing unit and app stays active for a distance of up to 100ft. | Test normal functionality of the smart cricket bat's operations at 10ft intervals ranging from 0ft to 100ft, or until bluetooth cuts off. | TESTED: Bluetooth module and mock phone had strong connection until 230 ft, where the connection would cut off. | Gavin Dahl Pablo Barron
3.2.1.2 | System Latency | User swing analysis deliver to user via the app in no greater than 10s after the user's bat has struck the ball. | Take 20 practice swings with the bat, timing the time from the ball's impact on the cricket bat till the analyzed swing data is available to the user on app. | FAILED: As of current ML and App integration the process from hit to data available on app takes approximately 10 minutes | Full Team
3.2.1.4 | Wireless Connection Stability | Connection between sensing unit and smartphone app does not drop. | Sensing unit connected to smartphone app via bluetooth, set to default mode, and left to run for 1 hour. Connection is monitored via smartphone app. | TESTED: Device Bluetooth connection stayed strong and was able to send data for 5 hours 21 minutes and 6 seconds. | Gavin Dahl Pablo Barron
3.2.1.4 | Full Range of Motion | Sensing unit can measure the angle of the bat at a full 360°. | Sensing unit is attached to the pivoting arm on a protractor, the angle is tracked on both a | TESTED: Sensing unit tracks accurate | Gavin Dahl

| | | piece of paper and in a text file, and then compared. | degree of turn for all 3 axes
3.2.1.5 | Easy to Use GUI | The app is easily navigable to allow any person, regardless of technical skills, to use our device | Upload the app to a simulated android phone to view the clarity of the app | TESTED: App is able to run on physical device and does not crash | Pablo Barron
3.2.1.5 | Operation Time | System operates continuously on battery power for a minimum of 2 hours. | Sensing unit is turned on, set to default mode, and left to run for 2 hours. Power is monitored via a digital multimeter. | TESTED: Fully charged 500 mAh lipo battery can run for about 6 hours | Nolapat Pipitvitayakul
3.2.1.6 | Detection Range | Sensing unit can detect vibrations from at least 38in away when mounted on a bat. | Mount sensing unit on end of the cricket bat handle and hit the top of the bat 10 times to ensure full range. | TESTED: Hit from anywhere on bat registers movement in IMU. | Gavin Dahl
3.2.1.7 | Detection Accuracy | Sensing unit is able to detect a collision between ball and bat on any area of the cricket bat. | Mount sensing unit on cricket bat, measure data from hits in a variety of areas on the bat (at least 15) until it is confirmed there are no dead areas. | TESTED: IMU sensor leaves no dead zone on bat | Gavin Dahl
3.2.1.8 | Detection Sensitivity | Sensors are able to detect degrees of motion within 1 deg of change and is able to give changes in speed to 1 decimal places. | Mount sensing unit to cricket bat, connect to PC via microUSB, and watch real time data output of angle of bat and speed and compare to movements made in real life. | TESTED: IMU can detect the change in angle within 1 degree of sensitivity | Gavin Dahl
3.2.1.9 | Ease of Use | System is easily attached to the end of the handle of the cricket bat, is easily connected to the app via bluetooth, and is easy to calibrate during first time startup calibrations. Whole process should take no more than 5 minutes. | Use a stopwatch to measure how long it takes the user to mount the device, pair to phone, and do the calibration setup. | TESTED: Device takes 3 minutes and 28 seconds to set up, 2 minutes of which is calibration time. | Full Team
3.2.2.1 | Mass | Mass of the combined control system (MCU and IMU sensors), power system (Li-Po Battery and boost converter), and our housing unit, will weigh no more than 100g. | Use a digital scale to measure the weight of the combined unit. | TESTED: Took average of 10 weigh-ins of sensing unit in its entirety, averaged out to 85.89 ± 0.01 g. | Nolapat Pipitvitayakul Gavin Dahl

3.2.2.2 | Volume Envelope | The housing unit for the sensing device should be cylindrical shape, be no more than 70mm in diameter, and have a height of 35mm. | Measure inner and outer diameters and height of the created housing unit for sensors. | TESTED: Outer diameter is 68mm and the height of the device is 36mm | Nolapat Pipitvitayakul Gavin Dahl
3.2.2.3 | Mounting | The sensing unit is able to be mounted to the handle of any cricket bat and can lock securely into place. | Use the developed mounting device to mount the sensing unit onto the end of the handle of the bat, and do various shack and shock tests to confirm secure fit. | TESTED: Device does not detach from bat handle via outside forces. | Nolapat Pipitvitayakul Gavin Dahl
3.2.3.1.1 | Input Voltage (MCU) | The input voltage for our Beetle BLE board shall be between 5V -8V. | Use a multimeter to validate input voltage level. | TESTED: Boost Converter Output is 5V +-0.1 | Nolapat Pipitvitayakul
3.2.3.1.3 | Battery Charging Voltage and Current | The sensing unit has a 3.7V 150mAh Li-Po battery as its power supply. These can be charged through a microUSB cable that can supply a maximum 150mA of charge current with a 4.2V charge voltage. | Use a multimeter to validate voltage levels and charge current levels. | TESTED: Charge voltage is 4.2 V and maximum charge current is 150 mA | Nolapat Pipitvitayakul
3.2.3.2.1 | App Data Gathering via Bluetooth | The Android device should be able to receive data from our MCU via bluetooth | Upload the app to a simulated android phone and input different "dummy" data to see if the android device received the data | TESTED: Data is able to send without interruptions or skipping over lines | Pablo Barron
3.2.4.1 | Thermal Resistance | The system should be able to operate in environments with temperatures ranging from 0°C to 85°C. | Use a heating mechanism to raise temperature to 85°C and test systems functionality. Place system in cooling mechanism to lower temperature to 0°C and test systems. | TESTED: Device works in Texas summer of approx. 110°F and in winter at about 32°F. | Gavin Dahl
3.2.4.2 | Shock Tolerance | The IMU should be able to handle g shocks up to a max of 10,000g. | Test dropping IMU at differing heights and then use systems normal functionality to try to validate that IMU will still function after taking shocks more than 10,000 | TESTED: IMU and PCB can withstand shocks up to 200 g's (an approx 30 ft fall) and strongest expected hit is about 100 g's | Gavin Dahl

## Performance on Execution Plan

The execution plan was executed completely. Some tasks had to be completed out of their original order as there were many complications regarding the consumer application. There were two main problems, integration through bluetooth and integration with the machine learning. The bluetooth integration was a simple fix once the problem was finally discovered, however the machine learning integration took much longer than expected and by the end was only barely integrated and was missing a few of the key components desired by the sponsor, such as the process being fully

automatic. Besides that hiccup, however, the rest of the execution plan was completed,

### the project was mostly completed on time, besides said machine learning and

application compromise.

## Performance on Validation Plan

The validation plan was completed in full. The validation of all components gave expected results, such as IMU, bluetooth, and power system, however there was one validation requirement set by the sponsor that failed to be completed. The sponsor wanted the time it took to process the hit to be a minute at most, however after all the issues with the machine learning and app integration, that process takes about 9 minutes. The key cause of this is that the database used to house the machine learning to process the data is not automatic and takes about 8 minutes to simply export the data delivered from the phone, and once completed then takes about 1 minutes to process

and give the desired data from the data set given.

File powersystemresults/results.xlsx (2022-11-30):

Vin (V) | Iin (A) | Vout (V) | Pin (W) | Iout (A)
3 | 0.158 | 4.988 | 0.474 | 0.09502806736
3.7 | 0.123 | 4.975 | 0.4551 | 0.09147738693
4.2 | 0.101 | 4.976 | 0.4242 | 0.08524919614

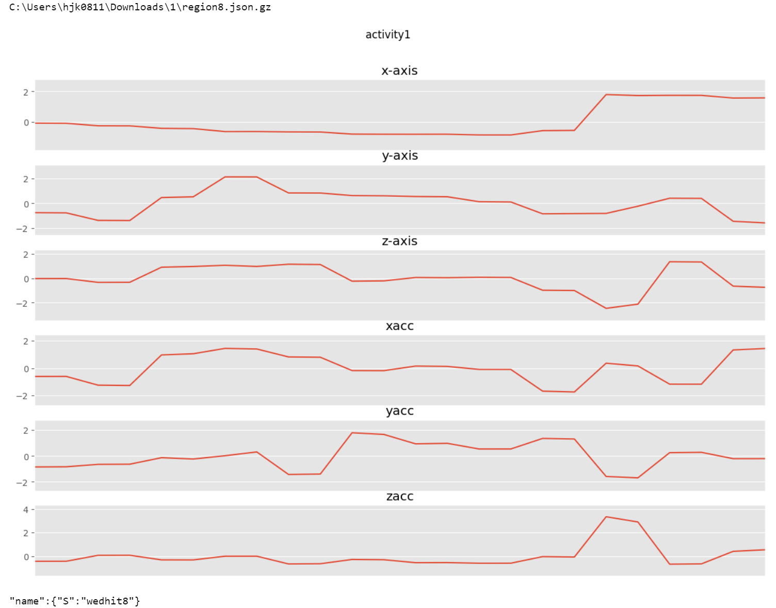
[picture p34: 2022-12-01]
ML Validation/ML Model Plots/wedhit8.png

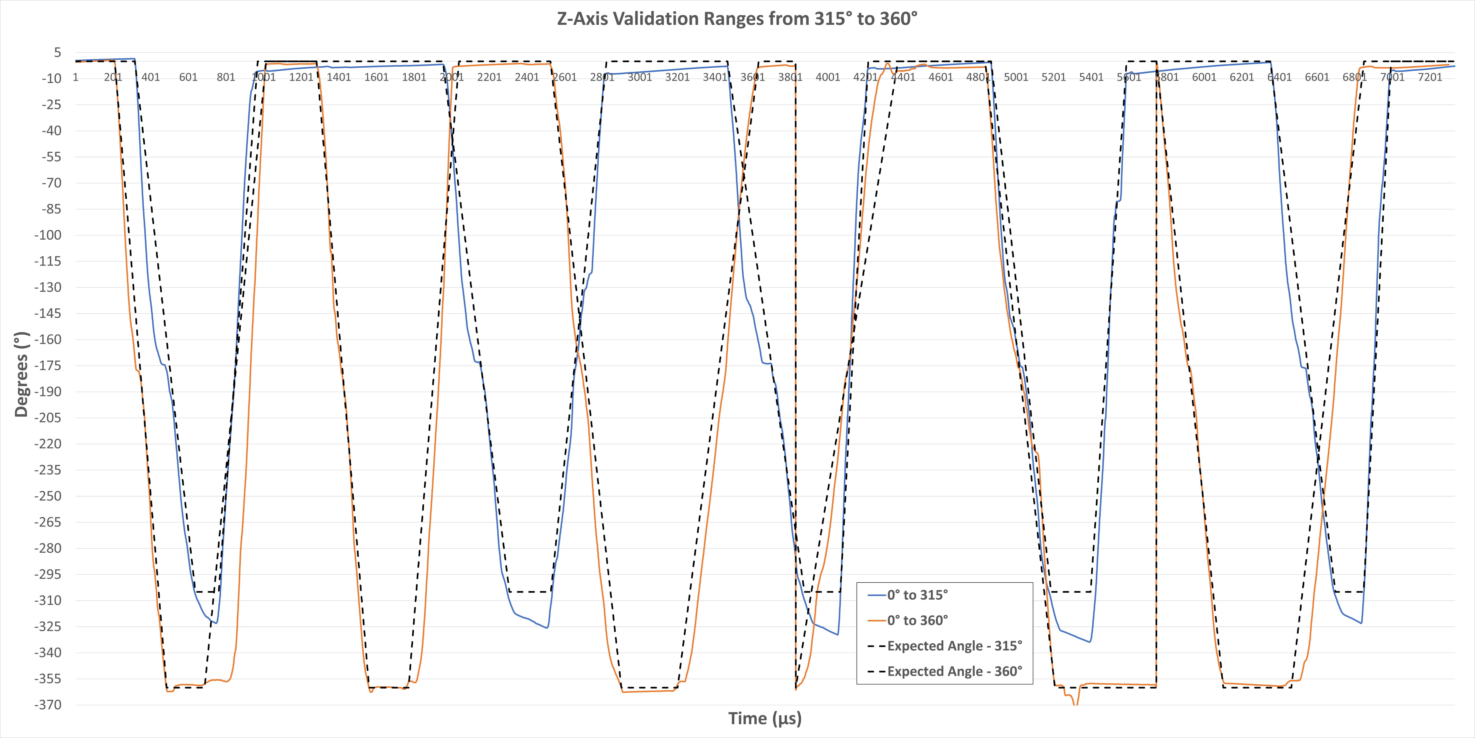
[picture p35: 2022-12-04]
IMU Validation Plots/GyroZAxis315to360.png

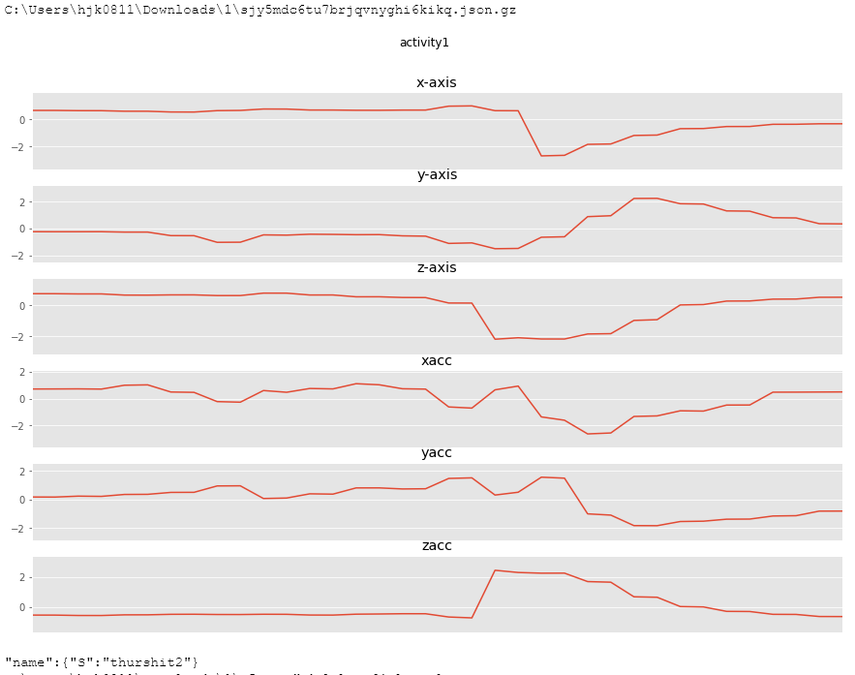
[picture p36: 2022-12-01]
ML Validation/ML Model Plots/thurshit2.PNG

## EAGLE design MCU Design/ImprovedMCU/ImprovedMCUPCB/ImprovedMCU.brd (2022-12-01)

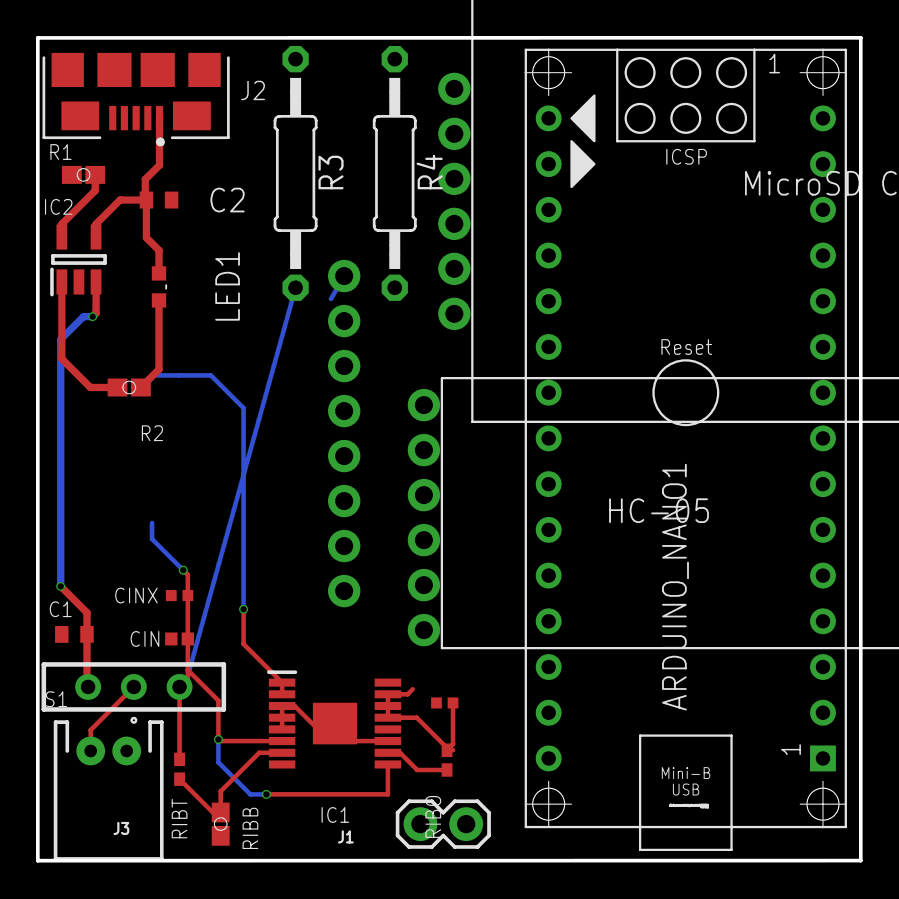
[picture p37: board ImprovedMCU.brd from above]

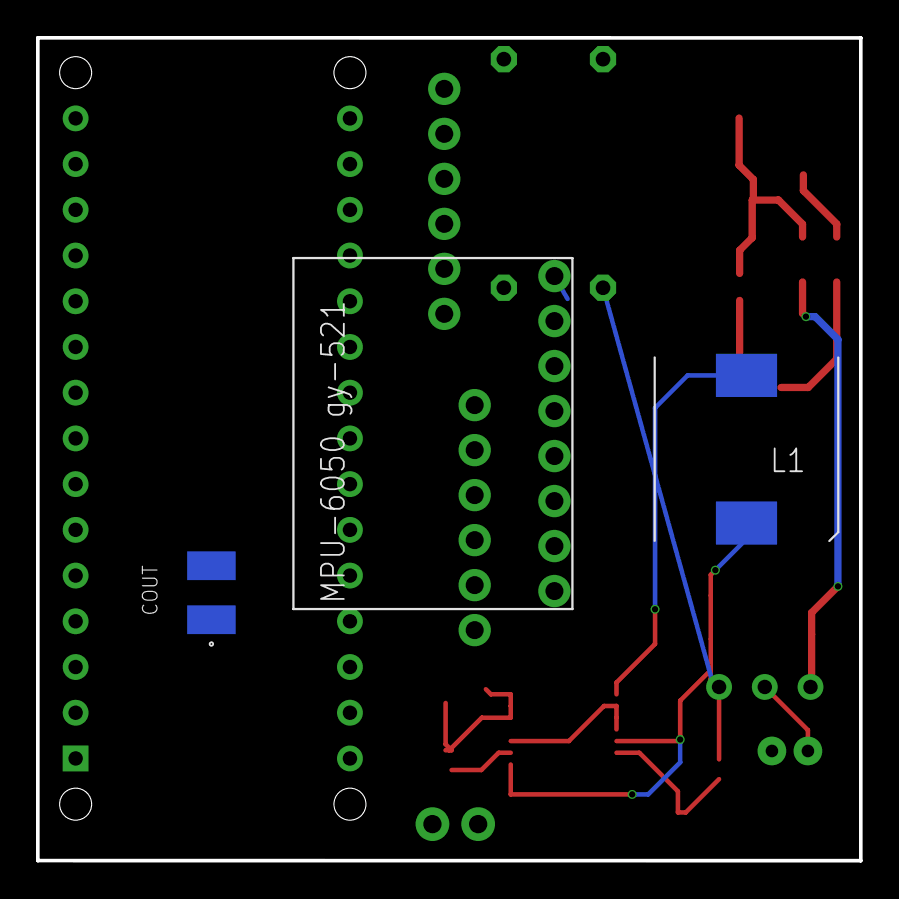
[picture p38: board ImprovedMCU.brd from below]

Board: 2 copper layers, 45.7 x 45.7 mm, 25 parts (3 on the bottom side), 12 nets.

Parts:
ARDUINO_NANO1: ARDUINO_NANO
C1, C2: GRM188R6YA475KE15D; CAPC1608X90N
CIN: 10uF; CAPC1005X70N
CINX: 100nF; CAPC1005X55N
COUT: 220uF; POSCAP_B1_B1S_B1G_B15G_B2_B2S
COUTX: 4.7uF; CAPC1005X55N
IC1: TPS61032PWP; SOP65P640X120-17N
IC2: MCP73831T-2ACI_OT; SOT95P270X145-5N
J1: 1X02
J2: AMPHENOL_ICC_-_FCI_10118192-0001LFAMPHENOL_ICC_-_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; AMPHENOL_ICC_-_FCI_10118192-0001LF_0
J3: JST-2-PTH
L1: 3.6uH; WE-PDF59
LED1: VLMS1300-GS08; VLMS1300GS08
R1: RC0603FR-076K65L; RESC1608X55N
R2: RC0603FR-07470RL; RESC1608X55N
R3, R4: 0207/12
RIBB: 390kOhm; RESC1608X55N
RIBO: 1.96MOhm; RESC1005X40N
RIBT: 1.96MOhms; RESC1005X40N
S1: 09.03290.01
U1: GY-521MPU6050; GY-521
U$1: MICROSDMODULE
U$2: HC-05

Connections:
GND: C1.2, C2.2, CIN.1, CINX.1, COUT.2, COUTX.2, IC1.3, IC1.4, IC1.5, IC1.8, IC1.11, IC1.16, IC1.17, IC2.2, J1.2, J2.5, J3.1, R1.2, R4.2, RIBB.1, U1.GND, U$2.GND
unnamed: J3.2, S1.1
unnamed: IC1.10, RIBO.2
unnamed: IC1.7, RIBB.2, RIBT.1
unnamed: LED1.2, R2.1
PROG: IC2.5, R1.1
S$2: COUTX.1, IC1.13, IC1.14, IC1.15, RIBO.1
STAT: IC2.1, R2.2
SW: IC1.1, IC1.2, L1.2
VBAT: CIN.2, CINX.2, IC1.6, IC1.9, L1.1, R3.1, RIBT.2, S1.3
VCHARGE: C1.1, IC2.3, S1.2
VUSB: C2.1, IC2.4, J2.1, LED1.1

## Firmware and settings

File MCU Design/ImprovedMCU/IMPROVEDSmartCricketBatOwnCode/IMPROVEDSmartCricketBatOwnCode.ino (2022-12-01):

//I2Cdev and MPU6050 must be installed as libraries
#include "I2Cdev.h"
#include "MPU6050_6Axis_MotionApps20.h"  //or #include "MPU6050.h" // but motion apps has included
#include "SoftwareSerial.h"

//Arduino Wire librabry is required if I2Cdev I2CDEV_ARDUNIO_WIRE implentation is used
#if I2CDEV_IMPLEMENTATION == I2CDEV_ARDUINO_WIRE
#include "Wire.h"
#endif

MPU6050 mpu;

//default sensitivty of gyro = 250 deg, accel = +- 2 g
/* power, ground, SDA, SCL, and Interrupt pin will be used, must reassign the int pin to digital pin 2
   because our microcontroller has no INT pin
*/

// "OUTPUT_BINARY_ACCELGYRO" sends all 6 axes of data as 16-bit
// binary, one right after the other (ex: ). This is quickest method, and easy to parse
//#define OUTPUT_BINARY

// uncomment "OUTPUT_READABLE_EULER" if you want to see Euler angles
// (in degrees) calculated from the quaternions coming from the FIFO.
// Note that Euler angles suffer from gimbal lock (for more info, see
// http://en.wikipedia.org/wiki/Gimbal_lock)
#define OUTPUT_READABLE_EULER

// uncomment "OUTPUT_READABLE_REALACCEL" if you want to see acceleration
// components with gravity removed. This acceleration reference frame is
// not compensated for orientation, so +X is always +X according to the
// sensor, just without the effects of gravity. If you want acceleration
// compensated for orientation, us OUTPUT_READABLE_WORLDACCEL instead.
#define OUTPUT_READABLE_REALACCEL

// uncomment "OUTPUT_READABLE_WORLDACCEL" if you want to see acceleration
// components with gravity removed and adjusted for the world frame of
// reference (yaw is relative to initial orientation, since no magnetometer
// is present in this case). Could be quite handy in some cases.
//#define OUTPUT_READABLE_WORLDACCEL

#define LED_PIN 13
bool blinkState = false;

//Bluetooth Module Pins
#define rxPin 3
#define txPin 4

//defining functions
void calibration();
void meansensors();

// MPU control/status vars
bool dmpReady = false;  // set true if DMP init was successful
uint8_t mpuIntStatus;   // holds actual interrupt status byte from MPU
uint8_t devStatus;      // return status after each device operation (0 = success, !0 = error)
uint16_t packetSize;    // expected DMP packet size (default is 42 bytes)
uint16_t fifoCount;     // count of all bytes currently in FIFO
uint8_t fifoBuffer[64]; // FIFO storage buffer

//Binary Output of IMU Vars
int16_t ax, ay, az;
int16_t gx, gy, gz;

//for auto-calibration/offset caculation
bool startUpFinished = true; //CHANGE TO TRUE ONCE THE APP IS ALL SET UP AND MAKE A WAY TO RECIEVE THE INPUT OF THE BUTTON
int resumeDump = 0;
int receivedData = 0; //vaiable for data sent from app by user to tell MCU to start or stop, etc

//Change this 3 variables if you want to fine tune the skecth to your needs.
int buffersize = 500;     //Amount of readings used to average, make it higher to get more precision but sketch will be slower  (default:1000)
int acel_deadzone = 8;     //Acelerometer error allowed, make it lower to get more precision, but sketch may not converge  (default:8)
int giro_deadzone = 1;     //Giro error allowed, make it lower to get more precision, but sketch may not converge  (default:1)

//int16_t ax, ay, az,gx, gy, gz;

int mean_ax,mean_ay,mean_az,mean_gx,mean_gy,mean_gz,state=0;
int ax_offset,ay_offset,az_offset,gx_offset,gy_offset,gz_offset;

//Battery Percentage
float battPercent = 100.0;

// orientation/motion vars
Quaternion q;           // [w, x, y, z]         quaternion container
VectorInt16 aa;         // [x, y, z]            accel sensor measurements
VectorInt16 aaReal;     // [x, y, z]            gravity-free accel sensor measurements
VectorInt16 aaWorld;    // [x, y, z]            world-frame accel sensor measurements
VectorFloat gravity;    // [x, y, z]            gravity vector
float euler[3];         // [psi, theta, phi]    Euler angle container

//INTERRUPT Detection Routine
volatile bool mpuInterrupt = false;     // indicates whether MPU interrupt pin has gone high
void dmpDataReady() {
  mpuInterrupt = true;
}
///////////////////////////////////  BLUETOOTH  ///////////////////////////////////
SoftwareSerial SCBApp(3, 4); // connect to smart cricket bat app (RX | TX)
///////////////////////////////////   SETUP   ////////////////////////////////////
void setup() {
  //must set the int pin for our MCU
  attachInterrupt(digitalPinToInterrupt(2), dmpDataReady, CHANGE);
  // join I2C bus (I2Cdev library doesn't do this automatically)
  #if I2CDEV_IMPLEMENTATION == I2CDEV_ARDUINO_WIRE
    Wire.begin();
    TWBR = 24; // 400kHz/24 I2C clock (200kHz if CPU is 8MHz)
  #elif I2CDEV_IMPLEMENTATION == I2CDEV_BUILTIN_FASTWIRE
    Fastwire::setup(400, true);
  #endif

  // initialize serial communication
  // (115200 chosen because it is required for Teapot Demo output, but it's
  // really up to you depending on your project)
  Serial.begin(9600);
  SCBApp.begin(9600); //has to be 9600 bc software serial is unstable above it
  while (!Serial); // wait for Leonardo enumeration, others continue immediately

  // initialize device
  Serial.println(F("Initializing I2C devices..."));
  mpu.initialize();

  // verify connection
  Serial.println(F("Testing device connections..."));
  Serial.println(mpu.testConnection() ? F("MPU6050 connection successful") : F("MPU6050 connection failed"));

  // wait for ready
  Serial.println(F("\nSend any character to begin DMP programming and demo: "));
  while ((Serial.available() && Serial.read()) && (SCBApp.available() && SCBApp.read())); // empty buffer
  while (!Serial.available() && !SCBApp.available());                 // wait for data
  while ((Serial.available() && Serial.read()) && (SCBApp.available() && SCBApp.read())); // empty buffer again

  // load and configure the DMP
  Serial.println(F("Initializing DMP..."));
  devStatus = mpu.dmpInitialize();

  //change sensitivty of imu to be +-8 g 
  mpu.setFullScaleAccelRange(MPU6050_ACCEL_FS_8);
  // supply your own gyro offsets here, scaled for min sensitivity
  //THESE ARE BASIC PLACE HOLDER VALUES FOR THE OFFSETS, I WOULD STILL RECOMMEND USING THE CALIBRATE SENSORS FEATURE
  mpu.setXGyroOffset(-84);  //
  mpu.setYGyroOffset(84);   //
  mpu.setZGyroOffset(5);  //
  mpu.setXAccelOffset(-3947);   //-6824
  mpu.setYAccelOffset(-4303); //-645
  mpu.setZAccelOffset(10496); // 2315 will need to switch z and y i think for the real bat 

  // make sure it worked (returns 0 if so)
  if (devStatus == 0) {
    // turn on the DMP, now that it's ready
    Serial.println(F("Enabling DMP..."));
    mpu.setDMPEnabled(true);

    // enable Arduino interrupt detection
    Serial.println(F("Enabling interrupt detection (MCU external interrupt digital pin 2)...")); //CHANGED
    attachInterrupt(digitalPinToInterrupt(2), dmpDataReady, RISING); //changed first parameter from 0 to digitalPinToInterrupt(2)
    mpuIntStatus = mpu.getIntStatus();

    // set our DMP Ready flag so the main loop() function knows it's okay to use it
    Serial.println(F("DMP ready! Waiting for first interrupt..."));
    dmpReady = true;

    // get expected DMP packet size for later comparison
    packetSize = mpu.dmpGetFIFOPacketSize();
  }
  else {
    // ERROR!
    // 1 = initial memory load failed
    // 2 = DMP configuration updates failed
    // (if it's going to break, usually the code will be 1)
    Serial.print(F("DMP Initialization failed (code "));
    Serial.print(devStatus);
    Serial.println(F(")"));
  }

  // configure LED for output
  pinMode(LED_PIN, OUTPUT);

}

///////////////////////////////////   MAIN LOOP   ////////////////////////////////////
void loop() {
  /* receivedData = Serial.read();
   * if(receivedData == 48){  //if recieve (0) than do the calibration
   *    startUpFinished = false;
   * } 
   * //maybe make if statement for (1) that enables that actual function of the sensor(recording swing data and giving to app) for like 5 secs or smth
   */
   delay(100);    //helps with the data sent being all weird
   startUpFinished = false;
   if (SCBApp.available()){  //if bluetooth is avilable read any input from user
      receivedData = SCBApp.read(); //use to end and resart loop whenever
   }
   else{
      receivedData = Serial.read();
   }
   if(receivedData == 48){  //if input 0, do calibration state
      //function call for calibration
      calibrateDevice();
      if(startUpFinished == true){
          SCBApp.println("Calibration Complete"); //Calibration Complete, 53
      }
      else{
          SCBApp.println("Calibration Failed");   //Calibration Failed, 54
      }
   }
   else if(receivedData == 49){  //if input 1, exit main loop, pause IMU dump
      while(resumeDump = SCBApp.read()){
        if(resumeDump == 52){
          break;
        }
        else if (Serial.read() == 52){
          break;
        }
        else{
          delay(50);
        }
      }
   }
   else if(receivedData == 51){ //sending 3 give battery%
      printBattPercent();
   }
   else if(receivedData == 50){
      exit(0);
   }
   
 
  // if programming failed, don't try to do anything
  if (!dmpReady) return;

  // reset interrupt flag and get INT_STATUS byte
  mpuInterrupt = false;
  mpuIntStatus = mpu.getIntStatus();

  // get current FIFO count
  fifoCount = mpu.getFIFOCount();

  // check for overflow (this should never happen unless our code is too inefficient, besides when it does it right after setting inital offsets)
  
  if ((mpuIntStatus & 0x10) || fifoCount == 1024) {
    // reset so we can continue cleanly
    mpu.resetFIFO();
    //Serial.println(F("FIFO Reset!"));  //will mostly be clearing values found during offset calculations, so we can start fresh
  }
  else if (mpuIntStatus & 0x02) {     // otherwise, check for DMP data ready interrupt (this should happen frequently)
    // wait for correct available data length, should be a VERY short wait
    while (fifoCount < packetSize) fifoCount = mpu.getFIFOCount();

    // read a packet from FIFO
    mpu.getFIFOBytes(fifoBuffer, packetSize);

    // track FIFO count here in case there is > 1 packet available
    // (this lets us immediately read more without waiting for an interrupt)
    fifoCount -= packetSize;

#ifdef OUTPUT_BINARY
    mpu.getMotion6(&ax, &ay, &az, &gx, &gy, &gz);
    Serial.write((uint8_t)(ax >> 8)); Serial.write((uint8_t)(ax & 0xFF));
    Serial.write((uint8_t)(ay >> 8)); Serial.write((uint8_t)(ay & 0xFF));
    Serial.write((uint8_t)(az >> 8)); Serial.write((uint8_t)(az & 0xFF));
    Serial.write((uint8_t)(gx >> 8)); Serial.write((uint8_t)(gx & 0xFF));
    Serial.write((uint8_t)(gy >> 8)); Serial.write((uint8_t)(gy & 0xFF));
    Serial.write((uint8_t)(gz >> 8)); Serial.write((uint8_t)(gz & 0xFF));
#endif

#ifdef OUTPUT_READABLE_EULER
    // display Euler angles in degrees
    mpu.dmpGetQuaternion(&q, fifoBuffer);
    mpu.dmpGetEuler(euler, &q);
    Serial.print(millis()); //print current time
    Serial.print("\t");
    Serial.print("euler\t");
    Serial.print(euler[0] * 180 / M_PI);  //multiply the euler array by 180/pi to get it in degrees
    Serial.print("\t");
    Serial.print(euler[1] * 180 / M_PI);
    Serial.print("\t");
    Serial.print(euler[2] * 180 / M_PI);
    Serial.print("\t");

    //////Bluetooth Message////
    SCBApp.print(millis()); //print current time
    SCBApp.print("\t");
    SCBApp.print(euler[0] * 180 / M_PI);  //multiply the euler array by 180/pi to get it in degrees
    SCBApp.print("\t");
    SCBApp.print(euler[1] * 180 / M_PI);
    SCBApp.print("\t");
    SCBApp.print(euler[2] * 180 / M_PI);
    SCBApp.print("\t");
#endif

#ifdef OUTPUT_READABLE_REALACCEL
    // display real acceleration, adjusted to remove gravity
    mpu.dmpGetQuaternion(&q, fifoBuffer);
    mpu.dmpGetAccel(&aa, fifoBuffer);
    mpu.dmpGetGravity(&gravity, &q);
    mpu.dmpGetLinearAccel(&aaReal, &aa, &gravity);
    Serial.print("areal\t");
    Serial.print(aaReal.x);
    Serial.print("\t");
    Serial.print(aaReal.y);
    Serial.print("\t");
    Serial.println(aaReal.z);

    //////Bluetooth Message/////
    SCBApp.print("\t");
    SCBApp.print(aaReal.x);
    SCBApp.print("\t");
    SCBApp.print(aaReal.y);
    SCBApp.print("\t");
    SCBApp.println(aaReal.z);
#endif

//originally just for validation, but i think it gives better data overall
#ifdef OUTPUT_READABLE_WORLDACCEL
    // display initial world-frame acceleration, adjusted to remove gravity
    // and rotated based on known orientation from quaternion
    mpu.dmpGetQuaternion(&q, fifoBuffer);
    mpu.dmpGetAccel(&aa, fifoBuffer);
    mpu.dmpGetGravity(&gravity, &q);
    mpu.dmpGetLinearAccel(&aaReal, &aa, &gravity);
    mpu.dmpGetLinearAccelInWorld(&aaWorld, &aaReal, &q);
    Serial.print("aworld\t");
    Serial.print(aaWorld.x);
    Serial.print("\t");
    Serial.print(aaWorld.y);
    Serial.print("\t");
    Serial.println(aaWorld.z);

    //////Bluetooth Message//////
    SCBApp.print("\t");
    SCBApp.print(aaWorld.x);
    SCBApp.print("\t");
    SCBApp.print(aaWorld.y);
    SCBApp.print("\t");
    SCBApp.println(aaWorld.z);
#endif

    // blink LED to indicate activity
    blinkState = !blinkState;
    digitalWrite(LED_PIN, blinkState);
  }
  
}


///////////////////////////////////   FUNCTIONS   ////////////////////////////////////
void meansensors(){   //gets mean values of all 6 axes
  long i=0,buff_ax=0,buff_ay=0,buff_az=0,buff_gx=0,buff_gy=0,buff_gz=0;

  while (i<(buffersize+101)){
    // read raw accel/gyro measurements from device
    mpu.getMotion6(&ax, &ay, &az, &gx, &gy, &gz);
    
    if (i>100 && i<=(buffersize+100)){ //First 100 measures are discarded
      buff_ax=buff_ax+ax;
      buff_ay=buff_ay+ay;
      buff_az=buff_az+az;
      buff_gx=buff_gx+gx;
      buff_gy=buff_gy+gy;
      buff_gz=buff_gz+gz;
    }
    if (i==(buffersize+100)){
      mean_ax=buff_ax/buffersize;
      mean_ay=buff_ay/buffersize;
      mean_az=buff_az/buffersize;
      mean_gx=buff_gx/buffersize;
      mean_gy=buff_gy/buffersize;
      mean_gz=buff_gz/buffersize;
    }
    i++;
    delay(2); //Needed so we don't get repeated measures
  }
}

void calibration(){   //used to get the Gyro and Accel offsets using mean value at rest
  ax_offset=-mean_ax/8; //take the mean values of the IMU at start up, and divide by the IMUs sensitvity (+- 8gs in this case)
  ay_offset=-mean_ay/8;
  az_offset=(16384-mean_az)/8;  //the 16384 is compensating for the gravity

  gx_offset=-mean_gx/4;
  gy_offset=-mean_gy/4;
  gz_offset=-mean_gz/4;
  while (1){
    int ready=0;
    mpu.setXAccelOffset(ax_offset);   //set current value for offsets in, to see if the current offsets are good, or if need to keep going
    mpu.setYAccelOffset(ay_offset);
    mpu.setZAccelOffset(az_offset);

    mpu.setXGyroOffset(gx_offset);
    mpu.setYGyroOffset(gy_offset);
    mpu.setZGyroOffset(gz_offset);

    meansensors();
    Serial.println("...");  //let user know something is happening, not stuck in a loop

    //deadzone is equal to sensitivy of IMU device
    if (abs(mean_ax)<=acel_deadzone) ready++;   //if mean of axis is less than deadzone, then that offset is accurate and ready to implement in main loop
    else  ax_offset=ax_offset-mean_ax/acel_deadzone;  //else like before we devide mean by deadzone until it is less than 
                                                        // ( if mean is 64 then offset whould be 8 bc offset is in terms of sensitivity)
    if (abs(mean_ay)<=acel_deadzone) ready++; 
    else  ay_offset=ay_offset-mean_ay/acel_deadzone; 

    if (abs(16384-mean_az)<=acel_deadzone) ready++; 
    else  az_offset=az_offset+(16384-mean_az)/acel_deadzone; 

    if (abs(mean_gx)<=giro_deadzone)  ready++; 
    else   gx_offset=gx_offset-mean_gx/(giro_deadzone+1); 

    if (abs(mean_gy)<=giro_deadzone) { ready++; }
    else   gy_offset=gy_offset-mean_gy/(giro_deadzone+1); 

    if (abs(mean_gz)<=giro_deadzone){ ready++; }
    else   gz_offset=gz_offset-mean_gz/(giro_deadzone+1); 

    if (ready==6)  break;    //once all 6 axes are ready to return, we return to main loop
  }
}

void printBattPercent(){
  int sensorValue = analogRead(A0); //read the A0 pin value
  float voltage = sensorValue * (5.00 / 1023.00) * 2; //convert the value to a true voltage.
  float oldBattPercent = battPercent;
  battPercent = (voltage/4.2)*100;
  if(battPercent > 100.0){
    battPercent = 100.0;
  }
  else if(oldBattPercent < battPercent){
    battPercent = oldBattPercent;
  }  
  SCBApp.print(battPercent); //print the voltage to LCD
  SCBApp.print(" %");
  /*Serial.print(battPercent);
  Serial.println(" %");
  Serial.println(voltage);
  Serial.println(sensorValue);*/
  if (voltage < 3.3){ //set the voltage considered low battery here
    SCBApp.println("Low Battery");
  }
}

void calibrateDevice(){
  if (state==0){  //first, do state0 where the sensor data is read and averaged
      Serial.println("\nReading sensors for first time...");
      meansensors();
      state++;
      delay(500);
    }
    if (state==1) { //state1, is then done next, and it calculates the offsets needed for all the IMU values to be equal to 0
      Serial.println("\nCalibrating Bat Sensor...");
      calibration();
      state++;
      delay(500);
    }
    if (state==2) { //state2, set found values from state1 to the offsets
      meansensors();
      Serial.println("\nFINISHED CALIBRATING BAT SENSOR!");
      Serial.print("\nSensor readings with offsets:\t");
      Serial.print(mean_ax); 
      Serial.print("\t");
      Serial.print(mean_ay); 
      Serial.print("\t");
      Serial.print(mean_az); 
      Serial.print("\t");
      Serial.print(mean_gx); 
      Serial.print("\t");
      Serial.print(mean_gy); 
      Serial.print("\t");
      Serial.println(mean_gz);
      Serial.print("Your offsets:\t");
      Serial.print(ax_offset); 
      Serial.print("\t");
      Serial.print(ay_offset); 
      Serial.print("\t");
      Serial.print(az_offset); 
      Serial.print("\t");
      Serial.print(gx_offset); 
      Serial.print("\t");
      Serial.print(gy_offset); 
      Serial.print("\t");
      Serial.println(gz_offset); 
      Serial.println("\nData is printed as: acelX acelY acelZ giroX giroY giroZ");
      startUpFinished = true;
      mpu.setXAccelOffset(ax_offset);
      mpu.setYAccelOffset(ay_offset);
      mpu.setZAccelOffset(az_offset);
      mpu.setXGyroOffset(gx_offset); 
      mpu.setYGyroOffset(gy_offset);
      mpu.setZGyroOffset(gz_offset); 
    }
}

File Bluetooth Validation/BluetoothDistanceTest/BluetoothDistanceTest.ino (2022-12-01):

#include <SoftwareSerial.h>
SoftwareSerial BTserial(3, 4); // RX | TX

char c = ' ';
int distance = 10;
char total = 0;
 
void setup() 
{
    Serial.begin(9600);
    Serial.println("Arduino is ready");
 
    // HC-05 default serial speed for commincation mode is 9600
    BTserial.begin(9600);  
    BTserial.println("Bluetooth is ready");
}
 
void loop()
{
 
    // Keep reading from HC-05 and send to Arduino Serial Monitor
    if (BTserial.available())
    {  
        c = BTserial.read();
        Serial.print(c);
        if(c == 48){
          BTserial.print("BT connection at: ");
          BTserial.print(distance);  
          BTserial.println(" ft");
          distance = distance + 10;
        }
    }
 
    // Keep reading from Arduino Serial Monitor and send to HC-05 
} 

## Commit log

2022-11-30 ML DATA
    All data collected to train machine learning model
    [HitProcessing.xlsx]
2022-12-01 MCU Design
    Includes improved design with added microSD module for hard copy back-ups and switched microcontroller from Bluno BLE to Arduino Nano
    [ImprovedMCU.brd, ImprovedMCU.sch]
2022-12-01 Bluetooth Validation
    Bluetooth was validated by first walking 10 feet and sending the current distance away from user up until the current distance was not received on the users end (Distance reached ~220-240ft). The Bluetooth was then tested in a similar manner, however instead of sending data, the device was disconnected then reconnected at intervals of 30ft, until the device was no longer available for pairing (Device disappeared from available blueooth devices at ~230ft).
    [BluetoothDistanceTest.ino]
2022-12-01 Libraries Needed for Final PCB
2022-12-03 Demo Videos
    Collection of videos demonstrating how to set-up and use Smart Cricket Bat device.

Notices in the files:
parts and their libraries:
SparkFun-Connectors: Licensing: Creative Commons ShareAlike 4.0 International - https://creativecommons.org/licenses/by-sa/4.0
